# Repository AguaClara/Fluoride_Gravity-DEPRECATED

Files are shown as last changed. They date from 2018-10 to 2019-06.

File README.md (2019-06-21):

# Fluoride Gravity
Our goal is to fabricate a user-friendly gravity-powered fluoride removal system that will be used for research. We aim to make the system easily adjustable so that various parameters can be tested.

See the [Fluoride - Auto repository](https://github.com/AguaClara/fluoride) for more information and previous research.

## Research Advisor
Tigran Mehrabyan (tm545@cornell.edu)

## Current Members
- Sarah Huang (slh268@cornell.edu)
- Cindy Jin (cj359@cornell.edu)
- Simar Kohli (sk2523@cornell.edu)

## Reports and Presentations
* Summer 2018
  - [Summer 2018 Report](https://github.com/AguaClara/Fluoride-Auto/blob/master/Summer%202018%20fluoride%20report/Fluoride_Summer2018.md)
  - [Summer 2018 Symposium](https://docs.google.com/presentation/d/1ikR3Ti14HijdFI1jzeJO_98PFFImXd8VALmxmuq5RYY/edit?usp=sharing)
  - [Summer 2018 Final Presentation](https://docs.google.com/presentation/d/1D4V2ltnIMBQwnw8twaZLWcnoIz6U8TILRAwltYmkqi8/edit?usp=sharing)
* Fall 2018
  - [Fall 2018 Report](https://github.com/AguaClara/Fluoride_Gravity/blob/master/Fall%202018/Fluoride_Grav_Fall2018_Report.md)
  - [Fall 2018 Symposium](https://docs.google.com/presentation/d/1zUhva35X0-_1o3RLzeis4E_ulAN4rfLVFNWJWVaX3iM/edit?usp=sharing)
  - [Fall 2018 Final Presentation](https://docs.google.com/presentation/d/15C-QUAlcFC1fCtsf0PomJqXiPuu_jBoPrGk902efx8c/edit?usp=sharing) and [Video](https://youtu.be/a5wm8xVp81A)
* Spring 2019
  - [Spring 2019 Report](https://github.com/AguaClara/Fluoride_Gravity/blob/master/Spring%202019/Spring%202019%20Report.md)
  - [Spring 2019 Symposium](https://docs.google.com/presentation/d/1IK8bv_c6N9sp4tUEqnVD2FkNc-OZfOIvl0ROv4Z8EFA/edit?usp=sharing)
  - [Spring 2019 Final Presentation](https://docs.google.com/presentation/d/197Uz4GfzHwbOVoRKWKSrQXqSO1M8MqDV9xneFl9WAC0/edit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)
  - [Spring 2019 Final Presentation Video](https://www.youtube.com/watch?v=5M4wX4iei7Y)

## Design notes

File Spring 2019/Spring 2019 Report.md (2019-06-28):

# Fluoride Gravity, Spring 2019
#### Sarah Huang, Cindy Jin, Simar Kohli
#### May 10, 2019
This publication Fluoride, Spring 2019 was developed under Assistance Agreement No. SU-83695001 awarded by the U.S. Environmental Protection Agency to Cornell University. It has not been formally reviewed by EPA. The views expressed in this document are solely those of Sarah Huang, Cindy Jin, and Simar Kohli and do not necessarily reflect those of the Agency. EPA does not endorse any products or commercial services mentioned in this publication.

## Abstract
Fluoride contamination of water is a significant issue faced by nations and people across the globe and can lead to adverse consequences on health (e.g. muscle weakness and atrophy, weakness, fatigue). The Fluoride Gravity team’s objective is to develop a cost-effective, self-sufficient mechanism for extracting excess fluoride from drinking water. The Spring 2019 team hopes to further the gravity-powered system’s efficacy and potentially begin to run field-tests with the device. The application of such a device in real-world scenarios will be predicated upon success seen with the aforementioned field tests.

## Introduction
The majority of AguaClara plants are located in Central America, where the sources of surface water originate from rivers and mountain streams. AguaClara's mission of providing access to safe drinking water for all has motivated the AguaClara team to expand and develop new goals. By considering and analyzing the differences in drinking water collected from groundwater sources in other regions around the world, AguaClara can serve communities outside of Central America who are deprived of access to safe drinking water.

At some locations where there is little to no fluoride in drinking water, fluoride is added in for the purpose of strengthening teeth and deteriorating natural deposits [(NYC DEP, 2016)](http://www.nyc.gov/html/dep/pdf/wsstate16.pdf). However, there are detrimental consequences when there is an excess concentration of fluoride in the water being consumed by inhabitants in the area. For example, there has been moderate to high fluoride pollution in regions such as Algeria, Thailand, Ghana, India, and Iran, whose major source of drinking water comes from groundwater sources. The pollution of groundwater in these regions is due to the mobile dissolution of fluorite, apatite, and topaz from weathered rocks, increasing the levels of fluoride in the groundwater [(Bhattacharya and Samal, 2018)](http://www.isca.in/rjrs/archive/v7/i4/6.ISCA-RJRS-2018-028.pdf). The effects of consuming excess fluoride include dental, skeletal, developmental, neurological, endocrine, reproductive, and carcinogenic issues that affect the health of the communities in areas of high fluoride concentrations [(Bhattacharya and Samal, 2018)](http://www.isca.in/rjrs/archive/v7/i4/6.ISCA-RJRS-2018-028.pdf). Therefore, the World Health Organization (WHO) regulated the concentration limit for fluoride in drinking water to be 1.5 mg/L [(Water-related diseases, 2016)](https://www.who.int/water_sanitation_health/diseases-risks/diseases/fluorosis/en/).

In India, the Bureau of India Standards set an upper limit of fluoride concentrations in drinking water to be 1 mg/L [(Bureau of India Standards, 2012)](https://archive.org/details/gov.in.is.10500.2012). However, more than 65 million Indians consume drinking water above the recommended limit of 1.5 mg/L and some locations in India contain up to 20 mg/L, which risks the health of many communities [(LeChevallier and Au, 2004)](https://www.who.int/water_sanitation_health/publications/9241562552/en/).

AguaClara aspires to achieve the recommended limit of 1 mg/L or lower by the Bureau of India Standards and to implement the gravity-powered system of fluoride removal into the communities with excess concentrations of fluoride. The Fluoride Gravity team will be testing the gravity-powered apparatus with PACl and red dye substituted as fluoride to optimize fluoride removal to achieve residual concentration of less than 1 mg/L. If the gravity-powered fluoride removal apparatus operates in the optimal conditions of removing fluoride to a concentration of 1 mg/L, feasibility analysis on site will be performed to test whether the system can be used in the communities in India, which will allow AguaClara to provide access to safe drinking water in India and other locations that obtain water from groundwater sources.

## Literature Review
### Interaction between Polymeric Aluminum Hydroxide with Fluoride
When hydrolyzed, polyaluminum based coagulants, one of which is polyaluminum chloride, formed mono- and polymeric species [(Gebbie, 2001)](http://wioa.org.au/conference_papers/2001/pdf/paper6.pdf). The interaction between aluminum hydroxide polymer and fluoride led to the formation of several insoluble and soluble products depending on the ratio of total fluoride ion and aluminum ion concentrations, pH, and the total applied fluoride and aluminum concentrations [(Parthasarathy et al., 1986)](http://www.nrcresearchpress.com/doi/abs/10.1139/v94-310). When pH was less than 4, the predominant fluorocomplex was AlF due to the complete dissociation of polymeric aluminum. When the ratio of total fluoride ion and aluminum ion concentrations was between 0.5 and 1, fluoride was observed to precipitate, replacing some of the hydroxide ions in the aluminum hydroxide polymer. When the ratio of total fluoride ion and aluminum ion concentration was greater than 3, there is both precipitate and dissolved complexed fluoride present. It was observed that the optimal conditions for precipitating fluoride was a hydroxide to aluminum ratio of 2.5, a fluoride to aluminum ratio of 0.7, and a pH between 4 and 7. Therefore, experiments should aim to achieve the optimal hydroxide to aluminum and fluoride to aluminum ratios, as well as pH, predicted by literature.

### Mechanisms Governing Removal of Fluoride
Of the potential mechanisms that may play a role in the removal of fluoride with polyaluminum chloride, including surface adsorption, coprecipitation, and precipitation, it appeared that coprecipitation is the main mechanism [(Kowalchuk, 2011)](https://digitalrepository.unm.edu/cgi/viewcontent.cgi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). Coprecipitation is the contamination of a precipitate by an impurity that is otherwise soluble under the conditions of precipitation [(Randtke in Kowalchuk, 2011)](https://digitalrepository.unm.edu/cgi/viewcontent.cgi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). Occlusion and surface adsorption played major roles in this process.

### Interactions Among Fluoride, NOM, and Alum During Coagulation Process
Experimental results from jar tests illuminated mechanisms of behind fluoroaluminum complexation [(Herrboldt, 2016)](https://repositories.lib.utexas.edu/bitstream/handle/2152/39194/HERRBOLDT-THESIS-2016.pdf?sequence=1). When fluoride was present in the system with alum, the residual aluminum increased significantly, indicating that fluoride is likely forming a soluble fluoroaluminum complex. In the removal of fluoride, the presence of natural organic matter (NOM) caused a small decrease in fluoride removal from 50.1% to 45.8%, whereas NOM removal was greatly inhibited by the presence of fluoride [(Herrboldt, 2016)](https://repositories.lib.utexas.edu/bitstream/handle/2152/39194/HERRBOLDT-THESIS-2016.pdf?sequence=1). This indicates that in the removal of fluoride, fluoride was likely outcompeting NOM for complexation with aluminum or adsorption to aluminum solids.

In the precipitation of aluminum with fluoride, fluoride was predicted to act in the following manner: since fluoride is a negatively charged species, fluoride must overcome the negative charge repulsion between particles in order to allow for aggregation. In the precipitation of fluoride with aluminum, the disruption of charges due to the negative repulsion stops collisions and ultimately causes particles to be concentrated at smaller particle diameters [(Herrboldt, 2016)](https://repositories.lib.utexas.edu/bitstream/handle/2152/39194/HERRBOLDT-THESIS-2016.pdf?sequence=1). In this manner, fluoride may inhibit the aggregation of flocs by acting as a stabilizing agent or by inhibiting precipitation. It was hypothesized that fluoride prevented the growth of precipitates by inhibiting interactions between hydroxide and nearby particles. It was also hypothesized that, due to the way that fluoride can replace hydroxide in solids , the formation of aluminum hydroxide complexes would be disrupted.

### pH Dependence of Fluoride Removal
In a study by Gong et al. (2012), fluoroaluminum complexation was found to exhibit pH dependence. At pH values less than 5.0, almost all fluoride existed as fluoro-aluminum complexes, inhibiting its removal by coagulation. At pH levels greater than 8.0, fluoride almost exclusively as free fluoride, indicating that hydroxide has a greater affinity for aluminum at a higher pH [(Herrboldt, 2016)](https://repositories.lib.utexas.edu/bitstream/handle/2152/39194/HERRBOLDT-THESIS-2016.pdf?sequence=1). Thus, all experiments should be run in the optimal pH range for fluoride removal.

### Collection and Analysis of Fluoride samples
An Ion-Selective Electrode (ISE) fluoride probe is used to measure the fluoride concentration of a sample. The following quality-control procedures should be followed.

ISE fluoride probes can only detect solubilized fluoride, and would give inaccurate readings in the presence of Fe3+ and Al3+, such as in cases where polyaluminum chloride is added to the system. Total Ionic Strength Adjusting Buffer (TISAB) solution is added to samples to solubilize the fluoride in the sample and keep the sample at a constant pH of 5-5.5. Temperature should be kept constant with less than a 1 degree Celsius deviation [(EPA Method 9214)](https://www.epa.gov/sites/production/files/2015-12/documents/9214.pdf).

Polyethylene containers, instead of glassware, should be used, since fluoride can adsorb to glass. An Initial Calibration Verification standard and a Continuing Calibration Verification standard should also be used, consisting of solutions of known fluoride concentration within the mean expected fluoride concentration that should be tested. The ICV should be used to test the accuracy of the calibration curve and the CCV should be sued after every 10 samples to ensure that the fluoride probe has not drifted from the calibration curve. These controls should be within 10% of their known values. A control blank containing one part water and one part TISAB should also be used to enhance the accuracy of data in future experiments.

## Previous Work
A coagulation-sedimentation system was developed to extract fluoride from contaminated water. Multiple tests have been run by past teams to analyze the efficacy of the designed system using polyaluminum chloride (PACl) as a coagulant.

The Spring 2016 team continued to develop a more efficient system by testing PACl with clay [(Longo, 2016)](https://drive.google.com/file/d/0B9yahrdDmfVpQ0t0M2NUUkRRNHM/view). While the team was successfully able to create a floc blanket, the Summer 2017 deemed clay to be not as necessary as it increased the effluent turbidity of the system, [(Akpan et al., 2017)](https://github.com/AguaClara/Fluoride-Auto/blob/master/FluorideReportSp18.md), and therefore ran tests with just fluoride and PACl. However, it was soon realized that the system would begin to fail after just 10 hours. In conjunction with the Summer 2017 High Rate Sedimentation Team, a new reactor was able to boost the time to failure and allow for increased upflow velocities. It was determined that the most efficient upflow velocity was 1.5 mm/s [(Pang et al., 2018)](https://github.com/AguaClara/Fluoride_Gravity/blob/master/Fall%202018/Fluoride_Grav_Fall2018_Report.md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). The same team continued to conduct experiments with varying concentrations of PACl in order to determine the most effective concentration of PACl to be delivered to the system.

The 2018 cycle of teams managed to focus on developing a robust, gravity-powered system [(Akpan et al., 2017)](https://github.com/AguaClara/Fluoride-Auto/blob/master/FluorideReportSp18.md). The process through which this system works is displayed in the schematic below (Figure 1).

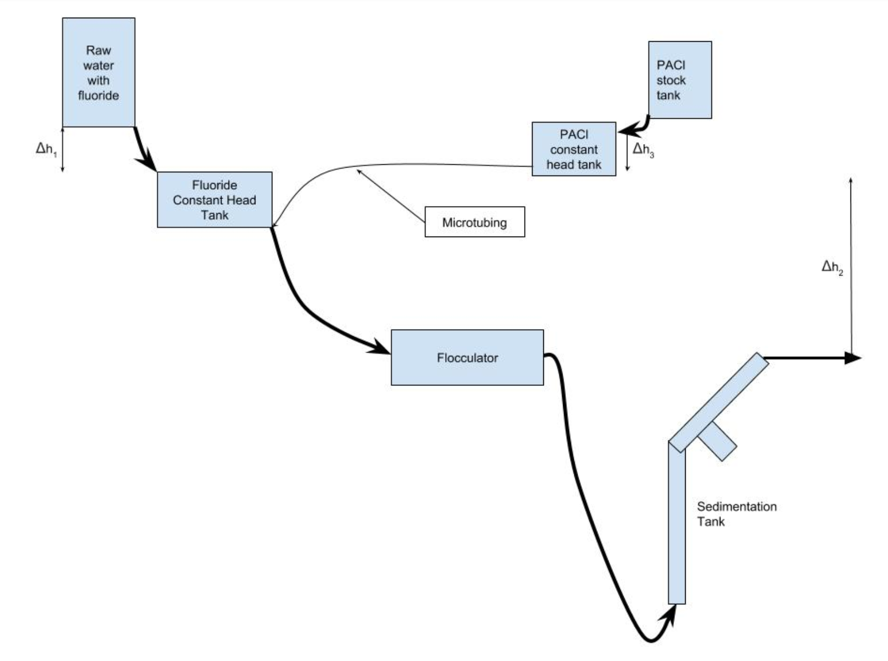
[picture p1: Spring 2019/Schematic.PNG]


**Figure 1:** A schematic for the gravity-powered system with differences in height generated power.

Some of the major designs of the model were created by the Spring 2018 team, and focused on deploying float valves to maintain a constant amount of water flowing through the system. Since the concentration of the PACl solution remained constant in the stock tank, a calculation of flow rate provided insight into the concentration of PACl actually entering in the system [(Pang et al., 2018)](https://github.com/AguaClara/Fluoride_Gravity/blob/master/Fall%202018/Fluoride_Grav_Fall2018_Report.md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).

The Summer 2018 team furthered the flexibility of the system by including sliders for controlling height differences between different tanks and pipes (Figure 2). This provided the ability for teams to adjust the flow rate within the system.

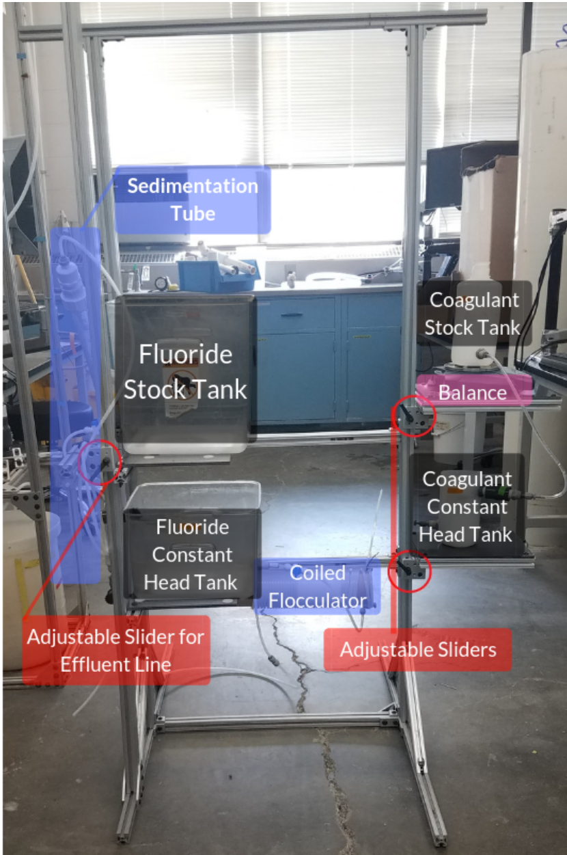
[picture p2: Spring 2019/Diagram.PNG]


**Figure 2:** Adjustments made by the Summer 2018 team to the set-up to allow for height variations.

The Summer 2018 team continued to conduct tests on varying PACl concentrations and fitted new data to the Langmuir adsorption spectrum created by the Fall 2017 team (Figure 3). Concentrations of fluoride (range: 3 to 20 mg/L) and PACl (range: 10 to 50 mg/L) were tested. A Langmuir isotherm was applied to the data to obtain a new uptake vs effluent model [(Pang et al., 2018)](https://github.com/AguaClara/Fluoride_Gravity/blob/master/Fall%202018/Fluoride_Grav_Fall2018_Report.md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).

The following equation was used: $$ \frac{C_e}{q_e} = \frac{1}{q_e}C_e+\frac{1}{K_L\cdot q_m} $$

where $C_e$ is the equilibrium concentration of the adsorbant, $q_e$ is the amount adsorbed at equilibrium, and $K_L$ and $q_m$ are Langmuir constants which are related to adsorption capacity and energy of adsorption.

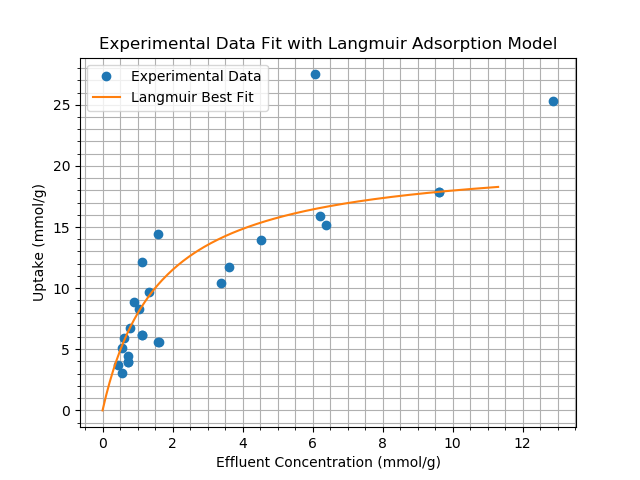
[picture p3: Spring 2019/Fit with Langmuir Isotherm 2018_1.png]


**Figure 3:** A Langmuir isotherm fitted with data from the Summer 2018 team. The calculated $R^2$ value was 0.7611.

In Fall of 2018, two teams were made from the original Fluoride team: [Fluoride Gravity](https://github.com/AguaClara/Fluoride_Gravity) worked to make the gravity-powered apparatus more efficient, and [Fluoride Auto](https://github.com/AguaClara/Fluoride-Auto) spearheaded the development of an adsorption model by running more bench experiments [(Pang et al., 2018)](https://github.com/AguaClara/Fluoride_Gravity/blob/master/Fall%202018/Fluoride_Grav_Fall2018_Report.md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).

Finally, the Fall 2018 team prioritized developing a mechanism or process for measuring coagulant flow rate within the system. An IV drip was installed within the system along with microtubing. While headloss still occurred, the team adjusted the height of the coagulant constant head tank to modify flow rate. The drip chamber was noted to substantially streamline the process of measuring flow rate [(Pang et al., 2018)](https://github.com/AguaClara/Fluoride_Gravity/blob/master/Fall%202018/Fluoride_Grav_Fall2018_Report.md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).

The goal of the Spring 2019 Fluoride team was to modify any necessary parts to the system developed over the past few years by previous Fluoride teams, begin to run comprehensive tests on red-dye within the system, and finally proceed to testing fluoride solutions within the system itself.

## Methods
### Experimental Apparatus
The gravity-powered apparatus was constructed as according to the fabrication manual in the [Fluoride Gravity Fall 2018 report](https://github.com/AguaClara/Fluoride_Gravity/blob/master/Fall%202018/Fluoride_Grav_Fall2018_Report.md).

### Redesigning of System
Despite the foundational work of the apparatus laid by the Fall 2018 team, it was determined the system needed to focus on having modifications in four major areas:

* Development of new method of introduction of polyaluminum chloride (PACl)
* Size reduction of fluoride constant head tank
* Increasing length of flocculator
* Addition of bottom geometry to sedimentation tube

However, most of the other aspects of the system were kept the same (e.g. sliders for moving tanks up and down, the presence of stock and constant head tanks, and the sedimentation tube itself).

The overall set up of the current system is shown in Figure 4.

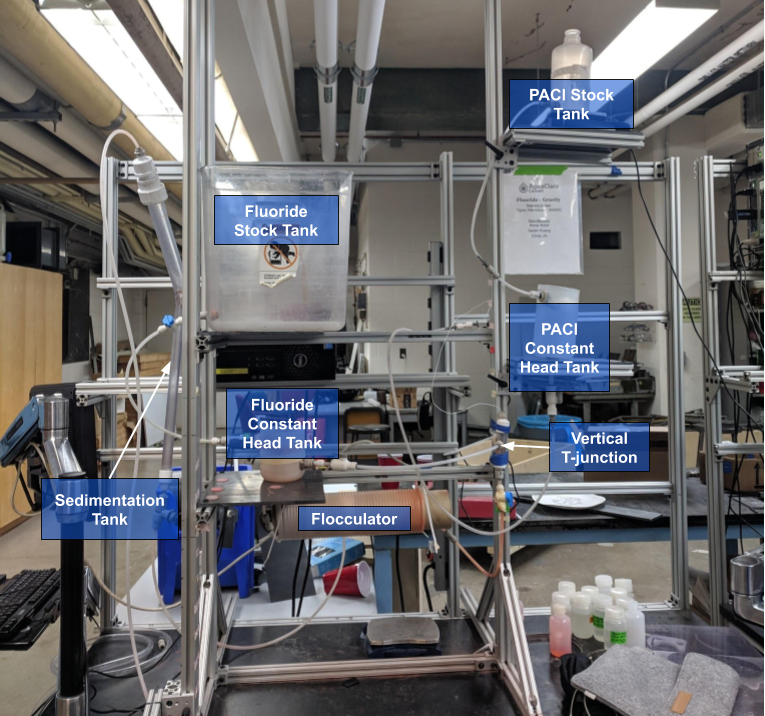
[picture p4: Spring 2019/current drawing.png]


**Figure 4:** An overview of the newly modified system.

### Introduction of Polyaluminum Chloride
The principal reason for modifying the method by which coagulant (PACl) was introduced into the system was the inefficiency of the IV drip chamber system set up by the Fall 2018 team (Figure 5).

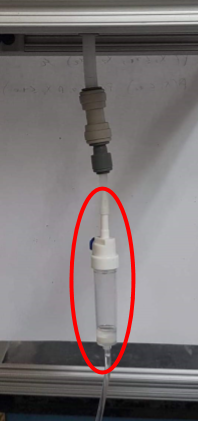
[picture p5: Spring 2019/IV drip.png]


**Figure 5:** The IV drip system that was implemented by Fall 2018 team. IV drip chamber was connected to coagulant constant head tank and flowed into flocculator.

When the system was run under the previous set-up, hydrostatic pressure from the flocculator would drive water into the drip chamber, filling it completely by the time the system was restarted. This resulted in the team having to consistently flush out the chamber. However, this led to air being introduced into the tubing and stopping flow within the system, entirely [(Pang et al., 2018)](https://github.com/AguaClara/Fluoride_Gravity/blob/master/Fall%202018/Fluoride_Grav_Fall2018_Report.md).

Several changes were thus made to optimize the ease of use of the apparatus. The IV drip chamber was removed due to previous difficulties in starting the system.

#### First Redesign: Direct Mixing in Fluoride Constant Head Tank
The T-joint that allowed PACl to be dosed directly into the flocculator was first removed, allowing the fluoride constant head tank to be directly connected to the flocculator (Figure 6).

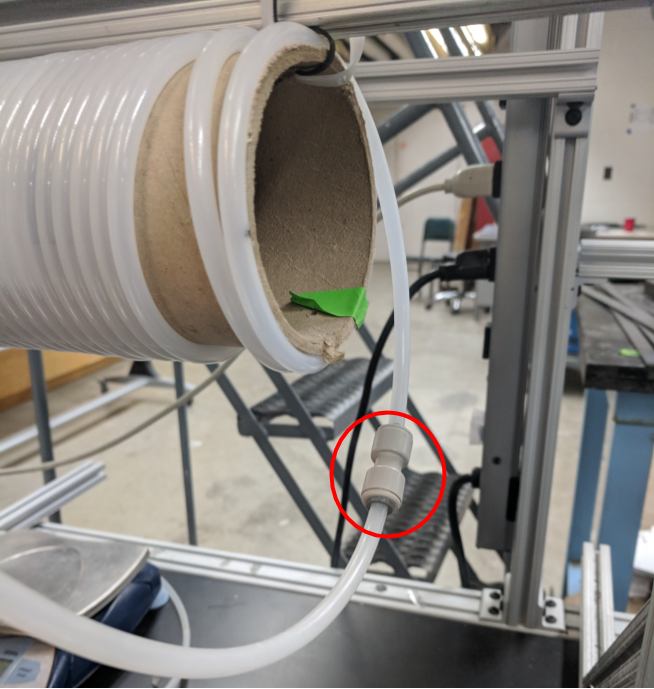
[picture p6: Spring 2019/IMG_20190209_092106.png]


**Figure 6:** New connection linking the fluoride constant head tank with the flocculator.

The team decided to directly drip the coagulant into the fluoride constant head tank by taping the end of the microtubing to the side of the tank (Figure 7). However, given that the size of the actual constant head tank was too large for proper mixing of the coagulant to occur, the constant head tank was reduced to a smaller size to allow for better mixing of the coagulant in the actual fluoride solution.

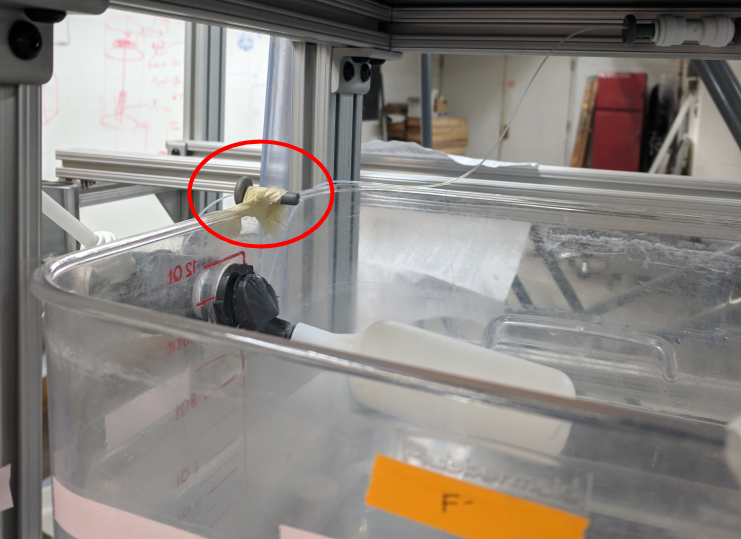
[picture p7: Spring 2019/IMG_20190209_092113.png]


**Figure 7:** Microbore tubing connected to the PACl system allows PACl to drip directly into the fluoride constant head tank.

However, two major problems were noted with this procedure. The first was that coagulation began in the tank as a result of dripping PACl directly into the tank. This could risk failure of the system if the coagulation blocked the outflow from the fluoride constant head tank. The second problem was a non-homogenous mixture was formed within the constant head tank, resulting in lower flocculation.

As a result, the team focused on creating a more effective drip system for introducing PACl while also being able to monitor flow rate/the rate of introduction of PACl into the system.

#### Second Redesign: Addition of T-Junction
The team determined that a new mechanism was necessary for effectively introducing the PACl into the system, one that would allow for easy calculation of flow rate, prevent re-introduction of air within the system, and create essentially a homogenous solution flowing into the flocculator.

As a result, the team decided that a T-junction could be used in between the outflow of the fluoride constant head tank and the flocculator. The third hole on the T-junction would be connected to a translucent pipe in which the PACl microtubing would drip the coagulant into (Figure 8). Holes were drilled in the translucent pipe to ensure that the dripping mechanism was open to atmospheric pressure.

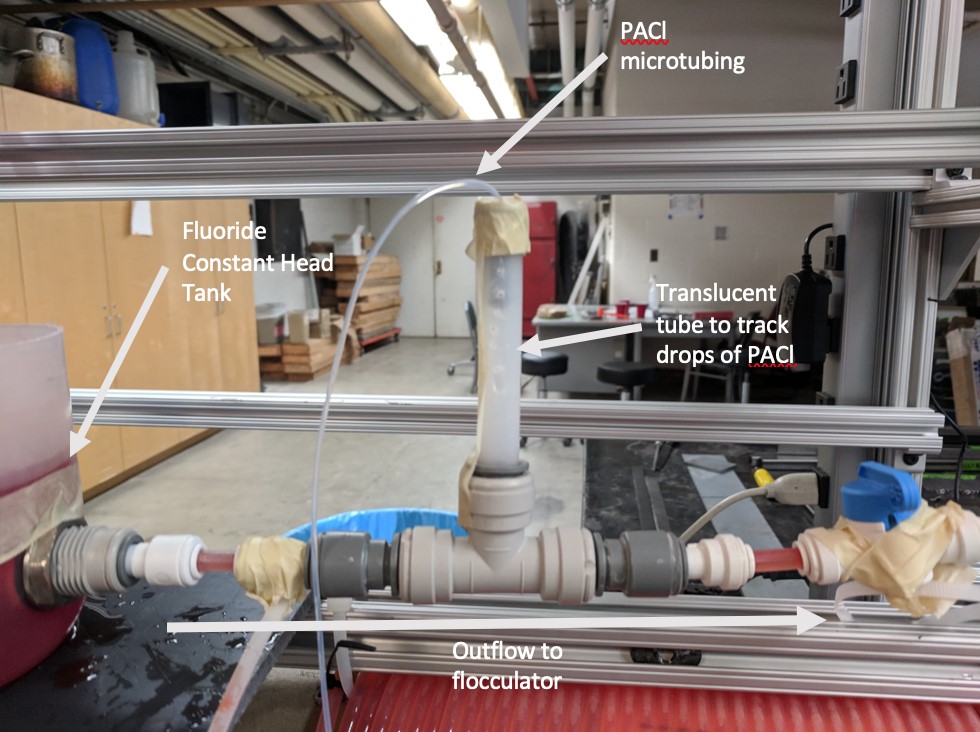
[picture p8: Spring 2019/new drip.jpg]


**Figure 8:** The system works by dropping PACl in to the solution flowing out of the system (towards the flocculator). Flow rate can be calculated by counting the volume of PACl dispensed in a certain period of time, producing a flow rate. Alternatively, the number of drops dispensed can be tracked by shining a light through the translucent tubing. The volume of one drop can be calculated, multiplied by the number of drops introduced in a time frame, and divided by the total time taken.

The overall set up of the system until this point is shown in Figure 9.

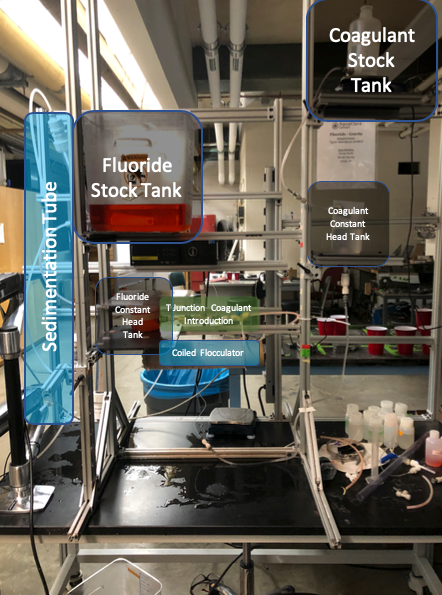
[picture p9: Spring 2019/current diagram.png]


**Figure 9:** An overview of the modified system.

#### Third Redesign: Fabrication of Clear T-Junction
Thus far, the system had experienced inconsistency in the size of flocs generated when PACl and red dye were mixed. It was hypothesized that the T-junction did not allow for the complete mixing of PACl and red dye.

In order to elucidate the mechanisms behind PACl and red dye mixing and binding, a clear T-junction was fabricated to be able to observe the behavior of PACl and red dye throughout the system.

The T-junction was fabricated by using a three inch segment of a clear PVC pipe that was 1 inch in diameter. Caps were fitted on both ends to allow connections to ¼ inch tubes. A fitting allowing for connection to a ¼ inch tube was drilled into the top of the PVC pipe, forming a T.  The drip system used previously was reconnected to the top of the fabricated T-junction.

The tube connecting the fluoride constant head tank and the T-junction was lengthened in order to prevent backflow, as backflow seemed to be an issue with the previous system. However, it is inconclusive whether this change was effective. A valve was also added between the fluoride constant head tank and the T-junction to allow for ease of maintenance in the case that the T-junction needed to be cleaned (Figure 10).

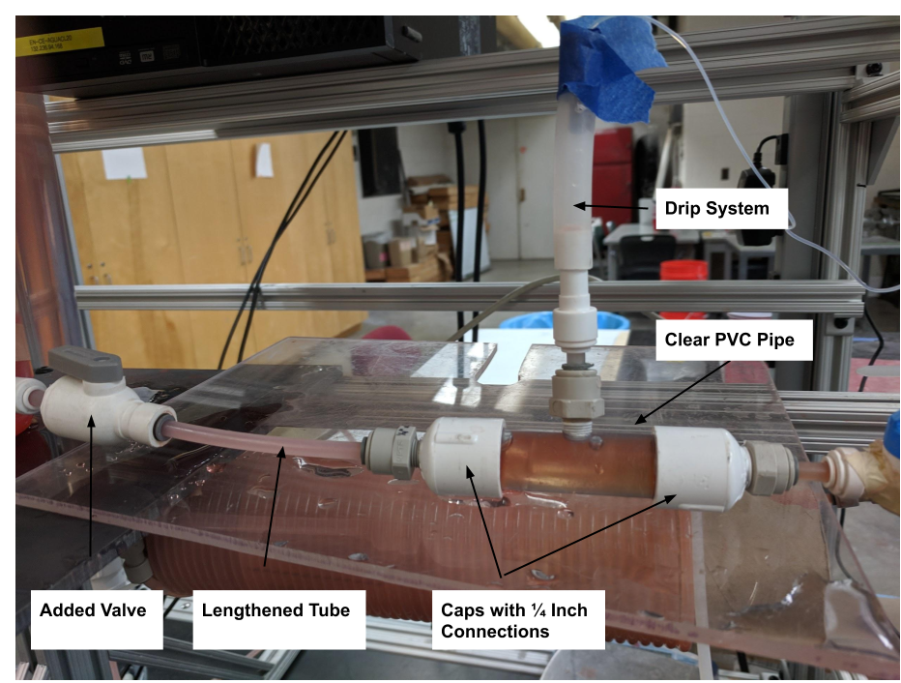
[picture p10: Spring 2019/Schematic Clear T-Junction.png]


**Figure 10:** A diagram of the fabricated T-junction and the new additions to the system, including the lengthened tube to prevent backflow and an added valve for ease of maintenance.

#### Fourth Redesign: Vertical Modification of T-Junction
After the development of a horizontal T-junction with a clear pipe (Figure 10), multiple tests were conducted on the system. However, it was noted that the system was continuing to fail to flocculate. When the clear piping within the T-junction was observed, it was noted that the red dye and PACl separated (either due to density differences or possible laminar flow). As a result, due to a lack of mixing between the two solutions, no flocs were being observed.

Thus, the team decided to turn the T-junction 90 degrees (thereby making it vertical) (Figure 11). The PACl was still being introduced from the top by microtubing; however, the solution now left the T-junction from the bottom. This was noted to contribute to better mixing, as the system began to flocculate and there was no further separation of the PACl and red-dye.

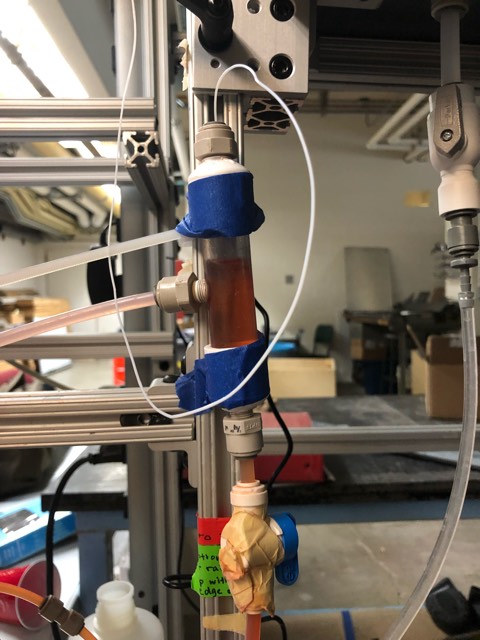
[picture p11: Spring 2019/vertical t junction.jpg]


**Figure 11:** Vertical T-junction with PACl introduced at top and dye introduced at the left

### Fabrication of New Flocculator
#### Increasing Flocculator Length
The length of the flocculator was increased to provide greater amount of time for flocculation. Specifically, the newly constructed flocculator coils around the main cardboard cylinder 49 times, and was constructed from 46 ft. of tubing (Figure 12).

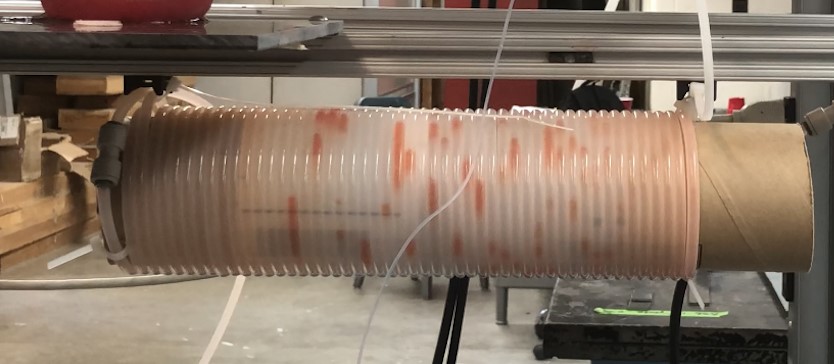
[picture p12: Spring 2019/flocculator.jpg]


**Figure 12:** The flocculator (lengthened to 46 ft. of tubing) in the system.

The reasoning behind increasing the flocculator’s length was that the PACl may need more time mixing effectively with the solution to produce the flocs necessary for filtration. Furthermore, providing more room and opportunity for collision between PACl molecules and the fluoride/red-dye within the system creates a more effective flocculation system and overall system.  

### Improving Sedimentation Processes
#### Addition of Bottom Geometry in Sedimentation Tube
The red dye flocs were observed to be clumping together at the bottom of the sedimentation tube, which resulted in the formation of a gel rather than a fluidized bed (Figure 13).



**Figure 13:** Before the addition of the bottom geometry, the formation of a gel is seen on the bottom of the sedimentation tube, which prevents the flow of clean water to exit the sedimentation tube and prevents the removal of the red dye particles from the PACl solution.

In order to prevent the formation of a gel at the bottom of the sedimentation tube and to effectively remove flocs, a bottom geometry was added to the bottom of the sedimentation tube to increase recirculation and collisions of the flocs to promote the formation of a fluidized bed (Figure 14). The bottom geometry was obtained from the [High Rate Sedimentation: Bottom Geometry team](https://github.com/AguaClara/HRS-Bot-Geo).

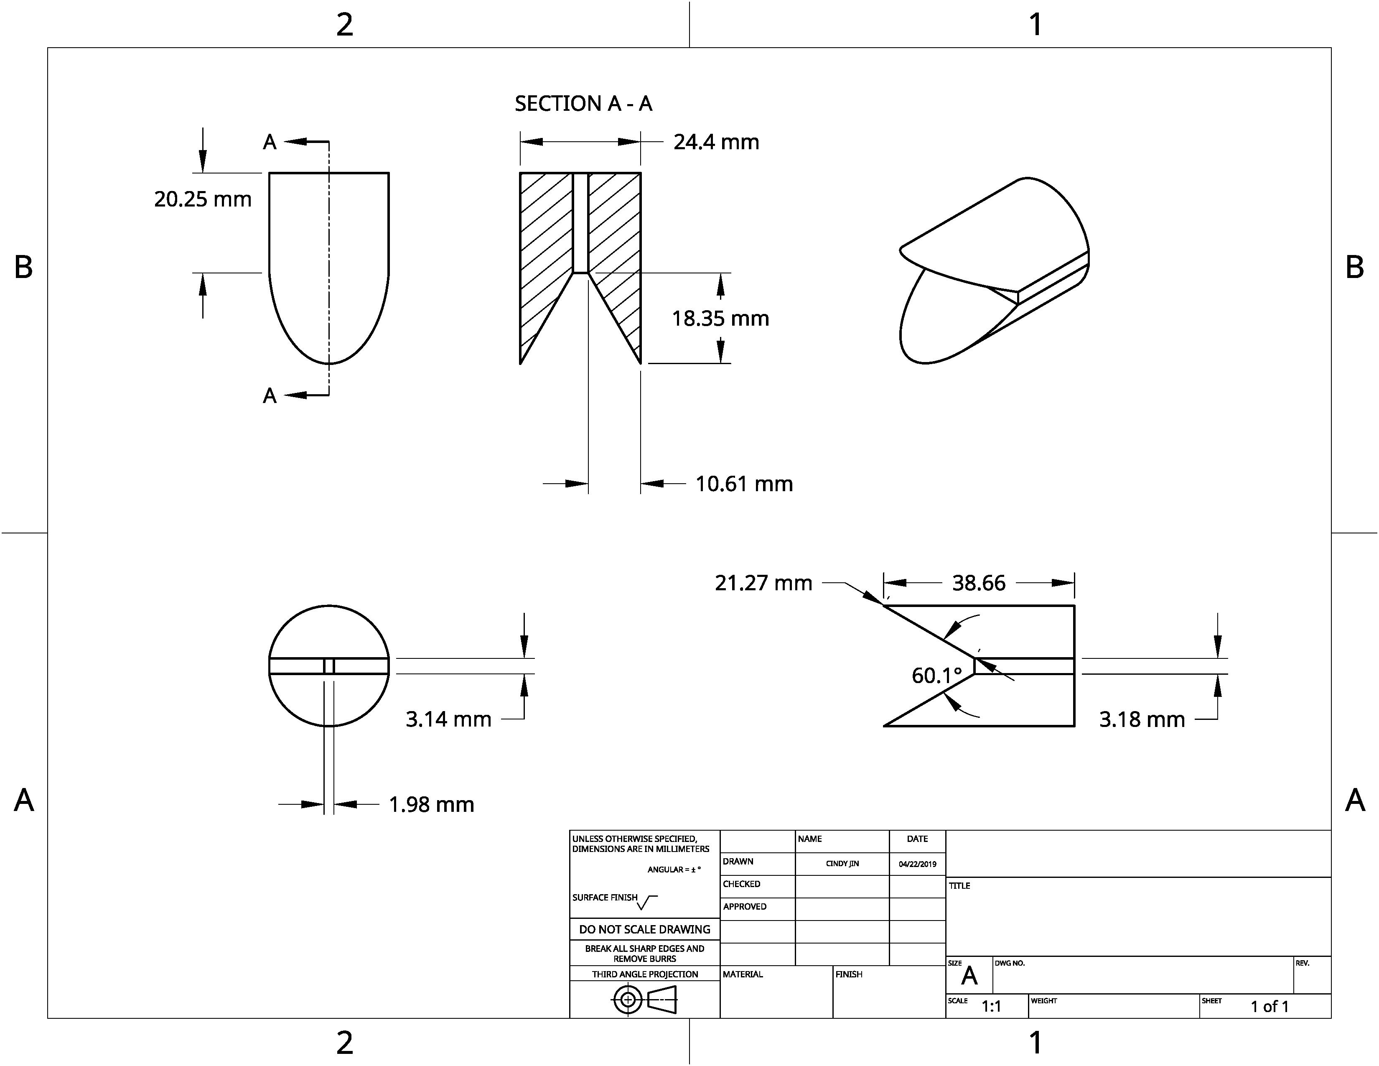
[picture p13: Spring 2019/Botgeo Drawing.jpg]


**Figure 14:** 2D scaled drawing of the bottom geometry that was added to the sedimentation tube.

The bottom geometry helped with the removal of flocs in the system because the slanted angle in the bottom geometry allowed for flocs to resuspend and change in flow direction rather than fall to the bottom of the sedimentation tube (Figure 15). The fluidized bed allowed for the flocs to move along the sedimentation tube and down the waste line, and the clean water to move past the waste line and exit the effluent line. Thus, the flocs were able to form a fluidized bed and increase the removal of red dye flocs from the PACl solution.



**Figure 15:** The formation of a fluidized bed is seen after the addition of the bottom geometry.

#### Jar Testing
In previous runs of the gravity powered system in which flocculation was successful, it was observed that red dye particles continued to float through the sedimentation tube regardless of its upflow velocity. That is, even when the system was stopped, all of the red dye flocs floated to the top of the sedimentation tube.

To test whether this result was specific to mechanics of flocculation that could perhaps change the properties of red dye flocs, a jar test was conducted. In one jar, a magnetic stirrer was used to rapidly mix the solution to increase collision rates. The other jar contained solution directly obtained from the system.

Plastic beakers with 420 $\mu$L of PACl was mixed with 100 $\mu$L of red dye in 400 mL of water. The solution was using a stir bar for 15 minutes before leaving the solution to settle.

This was compared to a solution of red dye-PACl flocs collected directly from the experimental apparatus after flocculation. The system concentration of PACl was 40 mg/L, and the red dye concentration used was identical to the independent test. The solution after flocculation was added to a beaker initially containing 200 mL of water to simulate conditions in the sedimentation tank. The flocculation solution was added to the beaker it was roughly the same color as the first independently created solution. The solution was not stirred and was allowed to settle directly after the addition of flocs.

## Results and Analysis
### Determining Coagulant Flow Rate
The flow rate of PACl was determined to have a linear relationship with the height differential between the fluoride constant head tank and the PACl constant head tank by the [Fluoride Gravity Fall 2018 team](https://github.com/AguaClara/Fluoride_Gravity/blob/master/Fall%202018/Fluoride_Grav_Fall2018_Report.md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). It was hypothesized that the decoupled PACl system would exhibit the same linear relationship with the change in height. The flow rate of the PACl entering the decoupled fluoride system was determined in two different methods: gravimetrically and volumetrically.

#### Gravimetric Method: Flow Rate of PACl During Direct Mixing of PACl Into Fluoride Constant Head Tank
The flow rate of the coagulant was determined by measuring the change in mass of the PACl stock tank over a period of time. This was then converted to volumetric flow rate. This was mode of measurement was conducted only with the direct mixing of the PACl into the fluoride head tank redesign of the system. The balance was connected to ProCoDA to measure the change in mass. The volumetric flow rate of the PACl coagulant entering the fluoride system was measured at several height differences (Figure 16).

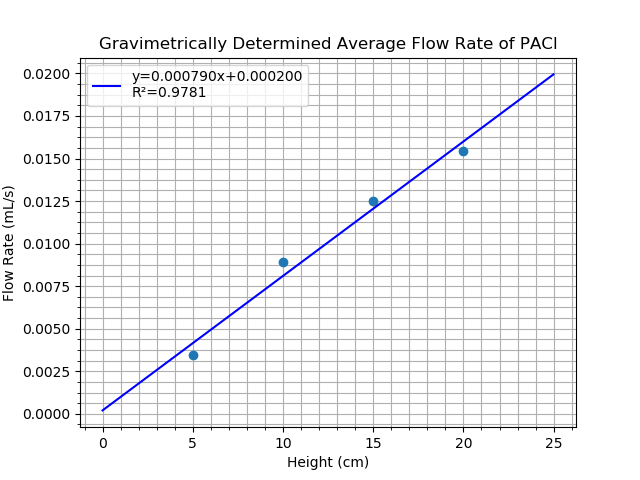
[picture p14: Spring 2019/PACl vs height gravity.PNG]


**Figure 16:** The flow rate of the PACl system was plotted against the change in height between the fluoride constant head tank and the PACl constant head tank. The data exhibits a strong positive correlation, indicating a direct relationship between flow rate and change in height.

The slope of the best fit line of the flow rate of the PACl system versus the difference in height between the fluoride constant head tank and the PACl constant head tank graph was calculated to be $7.9*10^{-4} mL*s^{-1} * cm^{-1}$, demonstrating the flow rate of PACl flowing into the fluoride system increases by $ 7.9*10^{-4} $ mL/s per cm of height difference raised.

#### Volumetric Method: Flow Rate of PACl After Addition of T-Junction
Using a 10 mL graduated cylinder, the flow rate of the PACl entering the fluoride system was also determined by measuring the time the PACl coagulant took to drip into the fluoride system to a volume of 2 mL. This was only conducted with the addition of the T-junction redesign of the system. The flow rate of the PACl entering the fluoride system was measured while varying the height difference between the fluoride constant head tank and the PACl constant head tank and doing three trials for each height difference. The data also exhibits a strong positive correlation indicating a direct relationship between flow rate and the difference in height between the coagulant constant head tank and the fluoride constant head tank (Figure 17).

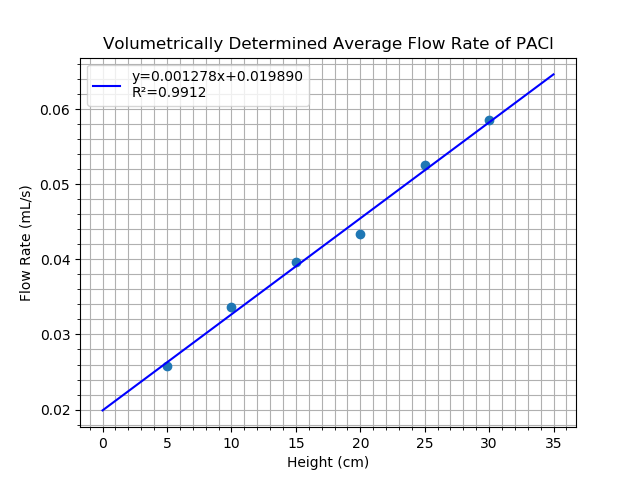
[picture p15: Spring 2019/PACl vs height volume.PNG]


**Figure 17:** The flow rate of the PACl system versus the difference in height between the fluoride constant head tank and the PACl constant head tank graph displaying a strong correlation between flow rate and change in height.

The slope of the best fit line of the flow rate of the PACl system versus the difference in height between the fluoride constant head tank and the PACl constant head tank graph was calculated to be $1.28*10^{-3} mL*s^{-1}* cm^{-1}$, which demonstrates the flow rate of PACl flowing into the fluoride system increases by $7.9*10^{-4}$ mL/s per cm of height difference raised.

The strong correlation implies that the relationship in the decoupled system operates in the same manner as the previously linked system with the IV drip chamber.

#### Volumetric Method: Flow Rate of PACl Using Vertical Clear T-Junction System

The flow rate of the PACl entering the system was recalculated after modifying our system to have an elongated microtubing for the PACl to enter the system in the vertical clear T-junction. The flow rate was calculated volumetrically by measuring the amount of time it took the coagulant to drip into a graduated cylinder to 10 mL for each height difference between the fluoride constant head tank and the PACl constant head tank. The data demonstrates a linear correlation between the height difference of the constant head tanks and the PACl flow rate entering in (Figure 18).

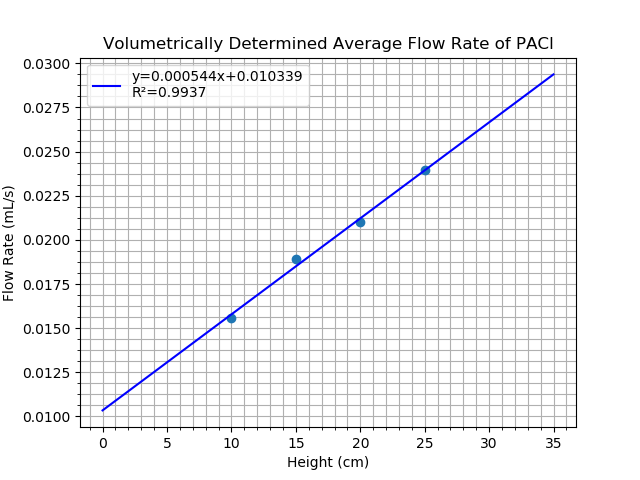
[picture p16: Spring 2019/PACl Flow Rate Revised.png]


**Figure 18:** The flow rate of the PACl system versus the difference in height between the fluoride constant head tank and the PACl constant head tank graph displaying a strong correlation between flow rate and change in height.

With the modified changes and elongated microtubing, the PACl flow rate entering the system decreased significantly as well as the rate in which the PACl flow rate changes with respect to the constant head tanks' height difference. This change in PACl flow rate occurred because the elongated microtubing increased the frictional head loss and residence time in the microtubing.

#### Comparison Between Gravimetric Method and Volumetric Method
The value of the coefficient of determination, $R^2$, was higher in the volumetric analysis graph (Figure 16) than the $R^2$ value of the gravimetric analysis graph of the PACl flow rate versus height (Figure 15). Therefore, the data collected from volumetric method is more accurate because the mass balance's readings was rounded to the hundredths place. The lower accuracy of the gravimetric method was due to the fact that the mass balance scale only measured the change in mass when the float valve in the constant PACl head tank opens, which gave inaccurate results as the float valve opens only when the water level drops. The mass did not change when the water level is level with the valve. Therefore, the change in mass was not constant which provides inaccuracy in the measurements.  However, the gravimetric method used ProCoDA and a mass balance with automated time and mass readings while the volumetric analysis was estimated with the human eye and timed manually, which accounted for human error. As a result, several trials were done to increase the accuracy and precision of the measurement of the volumetric flow rate of PACl entering the fluoride system.

The determination of the coagulant flow rate allowed the team to control and optimize the concentration of PACl entering the fluoride system.

### Determining Binding of PACl
#### First Redesign: Direct Mixing in Fluoride Constant Head Tank
The system was run in reverse, with red dye run through the PACl system to determine the extent of mixing. PACl solution was added to the fluoride system to determine the extent of coagulation and whether the solution would successfully flocculate. The system was run with a upflow velocity of 0.76 mL/s.

The red dye appeared to coagulate at the surface of the constant head tank. The water entering the flocculator was less red than the water in the constant head tank, implying that precipitation occurred in the constant head tank, lessening the extent of flocculation in the flocculator itself.

#### Second Redesign: Addition of T-Junction
The system was run in the correct orientation, with the red dye run through the fluoride tanks and PACl run through the PACl stock tanks. The PACl stock concentration was 1000 mg/L, and the red dye stock solution was diluted by a factor of 1/4000 (1 mL red dye for 4 L of water). The system was run at an upflow velocity of 0.48 mL/s.

The red dye was able to bind with PACl in the flocculator, allowing for successful flocculation. However, flocculation was inconsistent and the ability of the system to flocculate varied from day to day.

#### Third Redesign: Use of Clear T-Junction Horizontally
The system was tested with the new clear T-junction at different effluent flow rates to see if the PACl and red dye were mixing together effectively at the intersection. The clear T-junction made it possible to see that there was a clear layer of PACl settling on the bottom and not binding with the red dye (Figure 19).

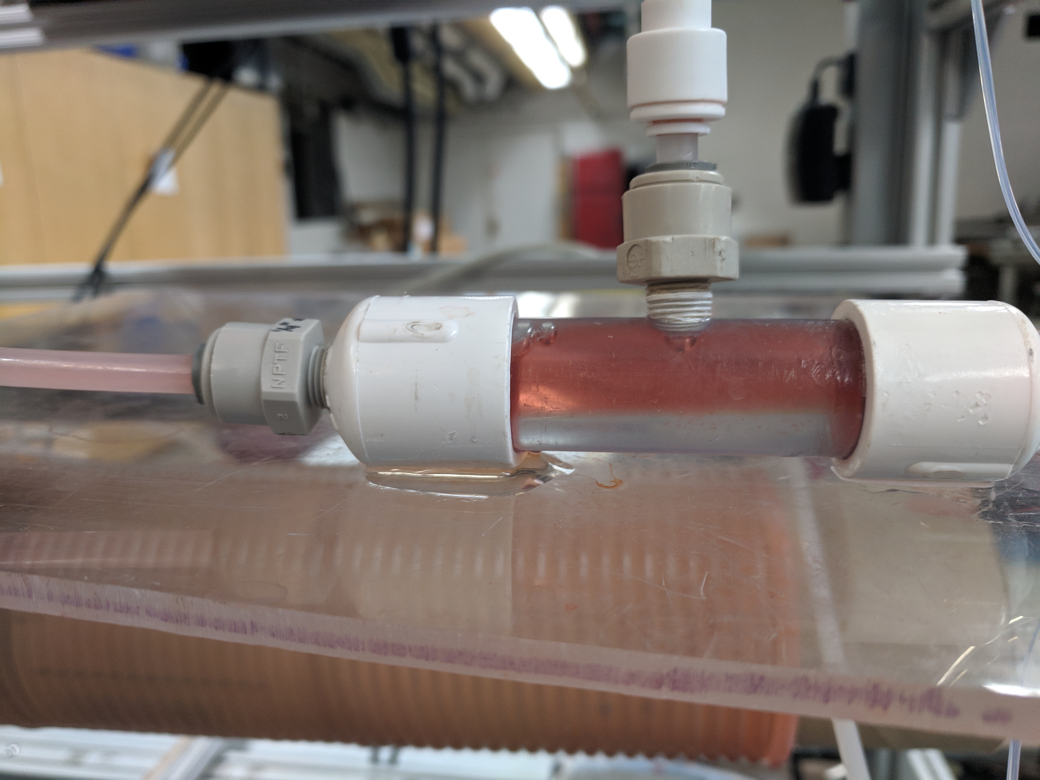
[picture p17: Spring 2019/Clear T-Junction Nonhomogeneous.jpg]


**Figure 19:** The introduction of PACl at the T-junction was seen to form a nonhomogeneous solution and the red dye and PACl were seen to not effectively mix together.

All tests were conducted at PACl flow rate of 0.0337 mL/s, which was the flow rate that previously allowed the system to flocculate. At the effluent rate of 0.69 mL/s, the PACl was seen to effectively bind with red dye as the formation of flocs were seen in the clear T-junction, but there were some flocs moving the opposite way of the fluid flow as seen in Figure 20, which may contribute a smaller flow rate of flocs entering the flocculator. At all other effluent flow rates, flocs were not observed.



**Figure 20:** At the system effluent rate of 0.69 mL/s, the red dye and PACl were seen to bind together and form flocs, but some of the flocs were seen to resist against the fluid flow in the clear T-junction.

These observations demonstrated that the red dye and PACl solutions were not effectively binding at the site of mixing and progressing to the flocculator for this concentration of PACl and all effluent flow rates. As a result, introducing PACl into the system in this manner was ineffective and should be revised.

### Determination of Effluent Flow Rate
In all prior experiments, the effluent flow rate was manually measured each time with a graduated cylinder. A curve based on the change in height of the effluent tube and the flow rate was established in order determine the flow rate of the system more easily.

To establish this curve, the effluent flow rate of the entire system was determined volumetrically. The team changed the height of the effluent pipe below the point of zero flow from 5 cm to 40 cm, with intervals of 5 cm. At each particular height, a 10 ml graduated cylinder was used to measure the volume of effluent water leaving the system in a particular period of time. Three trials were conducted and an average effluent flow rate was calculated, per height.

#### Effluent Flow Rate with Original T-Junction
The data was plotted, and a linear regression was fitted to measure the effluent flow rate at varying heights (Figure 21).

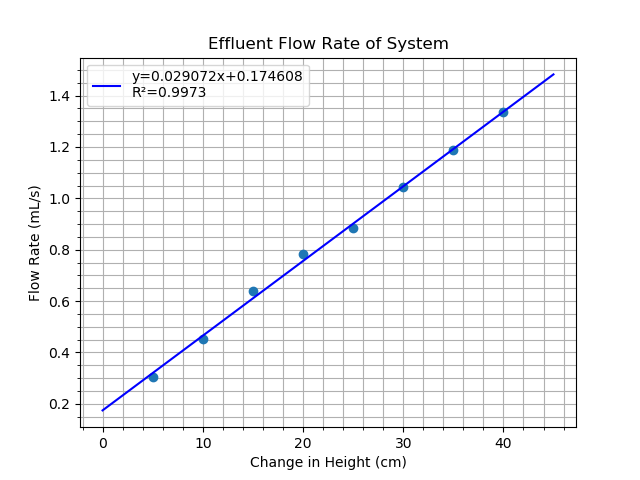
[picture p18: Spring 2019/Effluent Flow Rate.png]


**Figure 21:** The effluent flow rate graph determined volumetrically from a height difference of 0 cm to 40 cm from the point of zero flow using the original T-junction in the system.

When running the system at approximately 0.48 mL/s (with the effluent pipe located at the 10 cm mark), the system was noted to generate large flocs within the flocculator, indicating that the particular velocity of the system seemed to be working appropriately. Even when the system’s velocity was decreased to 0.34 mL/s, large flocs were still forming.

In light of this, the team decided to increase the effluent velocity of the system to analyze the impact of making the system faster. As a result, smaller flocs were noted to form, even to the point that the flow rate became too fast for significant flocs to form (flow rate > 30 cm).

However, from previous research, it was noted that a flow rate of 0.76 mL/s has been the most effective at floc formation as well as speed/efficiency of the system.

Yet, upon re-testing the system after determining the optimal effluent flow rate, as well as with other flow rates that previously worked (e.g. 0.48 mL/s, 0.38 mL/s, etc.), the system failed to flocculate. It was noted that the dye seemed to be lighter than usual, as well as the dye continued to clump within the sedimentation tank. The inconsistencies in flocculation persisted, but were solved upon using the vertical clear T-junction.

#### Effluent Flow Rate with Horizontal Clear T-Junction
The effluent flow rate of the system was tested again after lengthening the tube exiting the fluoride constant head tank and replacing the T-junction with a clear T-junction to accurately account for the changes to the system. The effluent flow rates of the system were tested in the same volumetric way and plotted against the change in height (Figure 22).

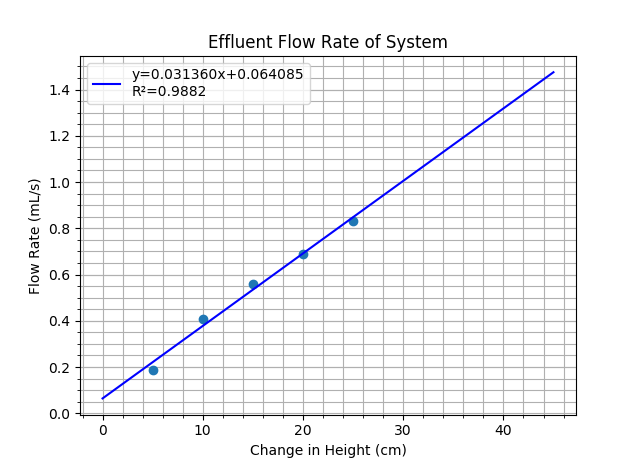
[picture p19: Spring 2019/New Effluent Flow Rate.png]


**Figure 22:** The effluent flow rate graph of the effluent flow rate determined volumetrically from a height difference of 0 cm to 40 cm from the point of zero flow using the redesigned system with the clear T-junction set horizontally.

Compared to the effluent flow rate of the system before the changes of the clear T-junction and the elongated tube, the effluent flow rate of the revised system was running at slower rates at the same height differences (Figure 20 and 21). The slower flow rates were due to the additional friction factors the red dye solutions experienced from the elongated tube. However, the rate at which the effluent flow rate changes with the difference in height was seen to be higher than that of the system before the changes because the slope of the best fit line of the effluent flow rate after the changes made is greater (Figure 21 and 22).

#### Effluent Flow Rate with Vertical Clear T-Junction System

The effluent flow rate of the system was tested again after vertically orienting the clear T-junction and lengthening the PACl microbore tubing to accurately account for the changes to the system. The effluent flow rates of the system were tested in the same volumetric way and plotted against the change in height between the constant head tanks (Figure 23).

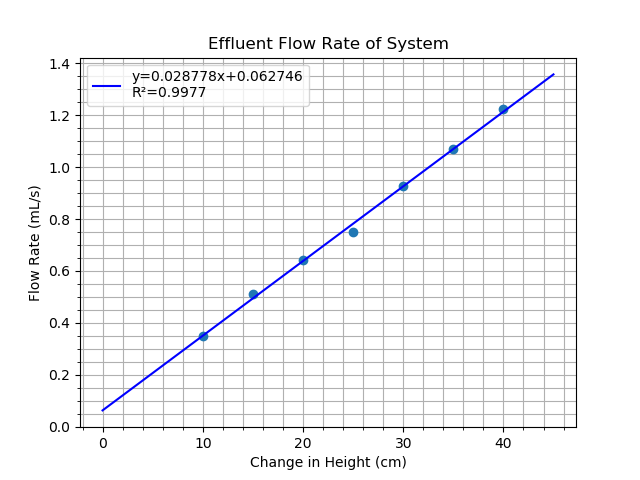
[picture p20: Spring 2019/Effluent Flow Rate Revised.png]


**Figure 23:** The recalculated effluent flow rate graph determined volumetrically from a height difference of 0 cm to 40 cm from the point of zero flow using the clear T-junction oriented vertically in the system.

 The effluent flow rate of the vertical T-junction system was running at slower rates at the same height differences compared to the effluent flow rate of the system before the change of orientation of the T-junction and the elongated microbore PACl tube (Figure 22, 23). The slightly slower flow rates were due to the additional friction head loss of the elongated microbore tubing that significantly slowed the flow rate of PACl entering the system. Furthermore, the rate that the effluent flow rate changed with the difference in height between the constant head tanks was seen to be lower than that of the system before the changes in orientation of the T-junction and the elongated PACl microtubing. This was exhibited by the fact that the slope of the best fit line of the effluent flow rate was smaller after the changes were made (Figure 22 and 23).

### Conditions for Flocculation
#### Effects of Effluent Flow Rate
In the first redesign of the system in which the microbore tubing dripped directly into the fluoride constant head tank, it was observed that no flocs or precipitates were observed when the system was run at the previously successful effluent flow rate of 0.76 mL/s. It was observed that the water exiting the effluent line had a large red dye concentration, suggesting an inability of PACl to bind with red dye at this high velocity.

When the system was run at 0.10 mL/s, a significantly lower velocity, small precipitates were observed. However, when the system was run at 0.13 mL/s, very large precipitates were observed in the flocculator (Figure 24).



**Figure 24:** At an effluent flow rate of 0.13 mL/s, flocculation was able to occur in the first redesign of the gravity powered system.

The implications of this result are the following:
The system must be run at a sufficiently low velocity that binding is able to occur but at a sufficiently high velocity that the number of collisions are maximized.

The system was sensitive to minute changes in the effluent velocity, indicating that there was a narrow optimal range with which the system was able to properly function.

#### Effects of Dosing of Polyaluminum Chloride
The ideal concentrations of PACl was thought to be modelled by the following Python program:
```python
import math as m
import numpy as np
from aguaclara.play import*

#Input the desired concentration of PACl through the system
Conc_PACl_exp = 40 * (u.milligram / u.liter)
#Input the desired upflow velocity in the sedimentation tube
upflow_velocity = 1.5 * (u.millimeter / u.second)

#Input your concentrations of your stock tanks
Conc_PACl_stock = 1000 * (u.milligram / u.liter)
Conc_fluoride_stock = 100 * (u.milligram / u.liter)

#Diameter of sedimentation tube
D_sed_tube = 1*u.inch
#Cross sectional area of sedimentation tube
Area_sed_tube = np.pi*(D_sed_tube**2)/4

#Calculate flow rate of system and input units of mL/s
Q_system = Area_sed_tube * upflow_velocity
Q_system.to(u.milliliter/u.second)
#Calculate the flow rate of PACl through the relation Q(PACl)*C(PACl)=Q(system)*C(system), where Conc_PACl_exp is the concentration of PACl in the system
Q_PACl = (Q_system * Conc_PACl_exp / Conc_PACl_stock).to(u.milliliter/u.second)
print(Q_PACl)

#Calculate the flow rate of fluoride through the relation Q(system)=Q(fluoride)+Q(PACl)
Q_fluoride = (Q_system-Q_PACl)
#Calculate the concentration of fluoride through the relation Q(system)*C(system)=Q(fluoride)*C(fluoride), where conc_fluoride_exp is concentration of fluoride in the system
conc_fluoride_exp = Conc_fluoride_stock * Q_fluoride / Q_system
print(conc_fluoride_exp)
```

In the second redesign of the experiment, this Python program was used to determine the ideal flow rate of PACl using an ideal concentration of PACl through the system, which was then mapped to the correct height using Figure 17. It was previously found that the ideal PACl concentration ranged from 10 mg/L to 50 mg/L; thus, the experiment was selected to run at a system concentration of 40 mg/L of PACl. The calculated flow rate of PACl that yielded this concentration was 0.034 mL/s, which corresponded to a height of 10cm (Figure 17). Under these conditions, it was found that an effluent flow rate of 0.48 mL/s yielded the largest flocs (Figure 25).



**Figure 25:** At an effluent flow rate of 0.48 mL/s and PACl flow rate of 0.034 mL/s, large flocs were observed in the flocculator of the second redesign of the system.

The system had thus far been unable to experience consistent flocculation despite using the height determined from the Python program.

It was first hypothesized that the system was unable to properly mix the red dye and PACl, preventing flocculation from occurring. However, after testing a variety of arrangements of the T-junction, including reverting it to old T-junction, and turning the T-junction vertically, it was found that flocculation was unable to occur in all of these arrangements.

It was then hypothesized that the system was deficient of PACl, and the microbore tubing was cut to decrease frictional headloss, allowing the PACl to enter at a high velocity. When testing against a variety of flow rates, flocculation still did not occur.

When the microbore tubing was made thinner, causing there to be more frictional headloss and thus a slower flow rate, the system was able to flocculate. Flocculation was observed at a PACl flow rate of 0.021 mL/s (8 cm) and an effluent flow rate of 0.68 mL/s (20 cm). After undergoing further testing, it was found that the system would flocculate under this same PACl flow rate at all effluent velocities. The effluent velocities dictated how large the observed flocs were, and it was found that an effluent flow rate of 0.51 mL/s to 0.75 mL/s (15 cm-25 cm) was most optimal.

This result suggested that dosing plays an essential role in the system’s ability to flocculate, and the necessary dose seemed to fall under a narrow range. The result likely deviated from the desired system concentration of PACl generated by the Python program because the length of the microbore tubing used in the Python analysis did not reflect that of the new system. Effluent velocity was important, but tended to govern the size of flocs rather than the existence of flocs. Further experiments should elucidate the relationship between the PACl dosage needed and the concentration of red dye (or fluoride) and whether the experimental results confirm the theoretical analysis done by the Python program.

### Improvement of Sedimentation Processes
#### Jar Testing
With the independently mixed solution, it was observed that the solution was first homogenous, but after some time, small particles similar to flocs were observed to form. When these flocs were allowed to settle, the majority of these flocs settled to the bottom, with only a small amount of flocs remaining on the surface of the water.

On the other hand, with the solution collected from the flocculator, it was observed that the majority of the flocs rose to the top of the solution rather than sinking (Figure 26).



**Figure 26:** The mechanics of the red dye was shown. The beaker on the left contained the solution acquired after flocculation and the beaker on the right contained the solution created through rapid stirring.

When both solutions were stirred once more with a magnetic stir bar, both solutions behaved in the same way. The majority of particles then settled, with a few floating to the top.

This seems to suggest that the flocculation process caused the water to act in a different manner than in normal mixing. It was hypothesized that a difference in pH may prevent mixing and the proper settling of flocs. However, when using pH strips that range between 1 and 14, the pH of both solutions were found to be approximately 8 (Figures 27 and 28).

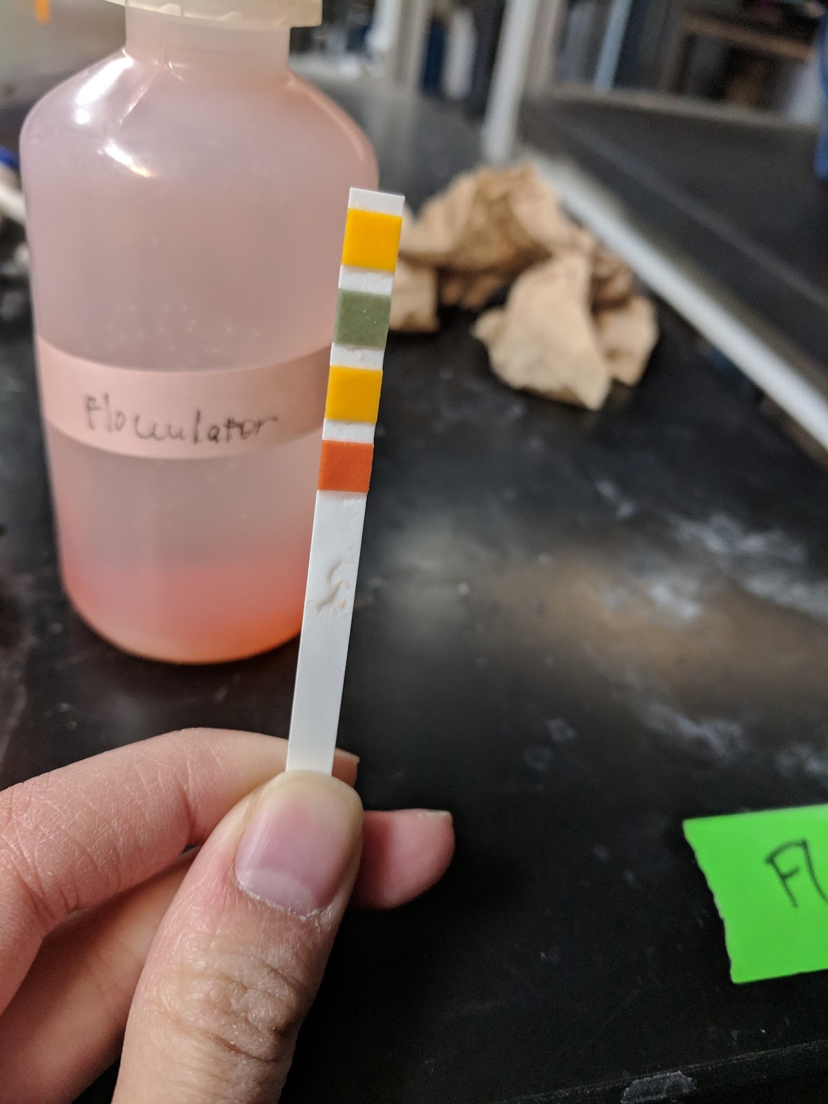
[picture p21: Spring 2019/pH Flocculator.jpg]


**Figure 27:** The pH of the solution collected from the flocculator sample was estimated to be 8 using a pH strip.

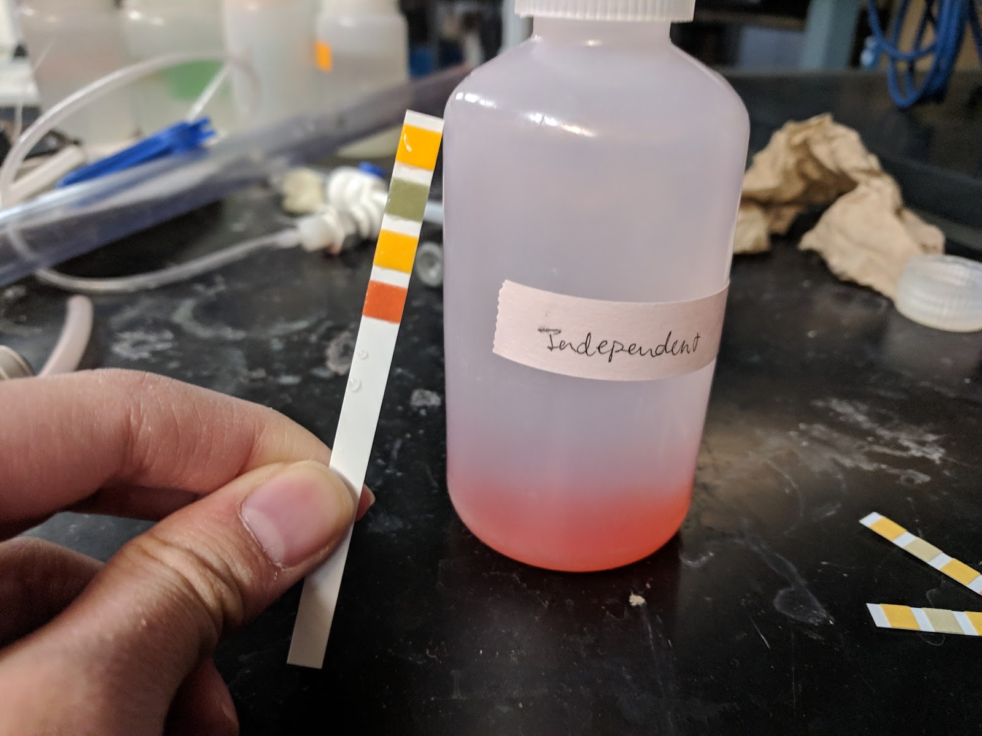
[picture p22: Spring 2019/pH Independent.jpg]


**Figure 28:** The pH of the independently mixed solution was also estimated to be 8 using a pH strip.

Both the independently mixed solution and solution collected from the flocculator had the same pH value, which ruled out the difference in pH potentially altering the mechanics of red dye, but the Fluoride Gravity team will verify this result using more sensitive pH strips or a pH meter.

When the apparatus was tested again with newly created red dye solution, the problem of small red dye flocs floating to the surface of the water in the sedimentation tube did not reoccur. This result seemed to be an anomaly.

#### Solving the Floating Floc Issue
As tests continued to be run on the system, it was noted that the red-dye flocs continued to float in the sedimentation tank, rather than settle. Despite the presence of the newly installed bottom geometry, this was continuing to occur.

The team had compiled multiple reasons for the observed phenomenon (as described earlier), for instance pH variations and dissolved solutes. However, the jar tests had clearly indicated that there was no variation in pH, nor did it appear that any contaminant solutes had made it into the solution.

After further analysis, it was hypothesized that the reason for the floating flocs could be dissolved gas. The source of this error/problem could be the usage of pressurized tap water that would result in the dissolution of air into the water. As a result, the flocs would be ‘pushed’ up through the water resulting in the “floating” behavior noted. This also seemed to explain why when the jars (from the jar test) were stirred, the flocs that were floating began to settle at the bottom. Some of the dissolved gas most likely escaped as stirring occurred, reducing the amount of gas and “floatation” of the flocs.

To solve this issue, the team began to utilize tap water that was filtered to remove any air from the water prior to using it in the system. The team immediately noticed that there were less flocs that were floating up the sedimentation tank, and a transition zone within the sedimentation tank was noticed. The flocs were sufficiently able to fall into the floc weir.

### Challenges
Over the course of the development and modification of the entire system, there are a couple of the challenges that the team is yet to overcome. Primarily, these fall under the following three categories:

* Flocculation
* Preventing air bubbles
* Scaling to fluoride

The first challenge is a rather recent one. Despite the team seeing tremendous success in flocculation early on in the testing phase, the system had no longer been flocculating at the same level as previously. While the team has some ideas as to why this is (potentially a disparity between using DI water and tap water or a difference in dosing that was unnoticed), it is still a challenge that needs to be overcome. Since the system’s success is predicated on the flocculation of the contaminant (e.g. red dye, fluoride), it is absolutely critical that the team - and future teams - work towards determining the reason for the sudden lack of flocculation.

Another issue that the team had constantly run into was the introduction of air within the system when flushing it, or even running the system. These air bubbles resulted in the significant slowing of the flow rate and reduced the mixing of the PACl and red dye in the flocculator and in the T-junction. Not only were these bubbles a potential source of error within the system and lack of flocculation, but removing these bubbles from the system was a time-consuming task. Thus, it is suggested that the team focuses on developing a system or methodology that can be effective in efficiently removing air bubbles.

Finally, a challenge with the system - in general - will be the scaling down of contaminant concentrations and the utilization of actual fluoride within the system. The primary concern was the system will not work effectively due to the incredibly small concentration of fluoride within the water. Especially given that consistent, large levels of flocculation were not occurring within a relatively high concentration of red dye (100 $\mu$L dye/400 mL of water), real-world (and significantly lower) concentrations of fluoride will surely not flocculate.

While the aforementioned challenges are significant in their difficulty, through multiple trials and modifications of the system, Fluoride Gravity could and will likely see success in the future.

## Future Work

The overarching goal of the Fluoride Gravity team is to determine the optimal method of removing fluoride from the water and creating the most compact system possible to be used for field testing. Future goals involve determine the dosages needed for optimal PACl binding at a variety of red dye, and eventually, fluoride concentrations, ensuring that flocculation is consistent every time the system is run, and testing the system's capacity to remove red dye at concentrations similar to natural concentrations of fluoride.

If flocculation is made consistent, efforts should move to creating an Onshape model for future deployment of the system in field testing.

## Conclusion

Proper mixing of PACl and red dye was necessary for flocculation and removal of fluoride, which was successfully visualized through the fabrication of a clear T-junction.

At too low of a flow rate of PACl entering the system, it was observed the precipitate formed was too small and the system velocity was too slow to have sufficient collisions for effective flocculation.

At too high of a flow rate of PACl entering the fluoride system, there were no precipitates formed and the effluent leaving the system contained both the PACl and red dye in solution.

The optimal flow rate of PACl entering the fluoride system was found in between the two extremes where the fluid is flowing at a high velocity to maximize collisions but not too high of a velocity such that the flocs break up. This velocity ranged from 0.45 mL/s to 0.76 mL/s, which corresponded to a change in height of the effluent line to be between 9.5 cm and 20 cm.

However, the system more highly depended on dosage. After the fabrication of the clear T-junction, the system was able to run at the PACl flow rate of 0.0206 mL/s.

After flocculation, the successful sedimentation of red dye experiments depended on the presence of a bottom geometry insert, but was able to form a fluidized bed after its addition.

The successes of the system imply that the reported system would be able to successfully remove fluoride from tap water. Once the experimental design is tested several times and able to be modeled optimally at all times, the design can be sent to communities with high concentrations of fluoride in their tap water for field testing and ultimately for water treatment to remove fluoride from drinking water systems.

## Bibliography
Akpan, P., Mehrabyan, T,. Sausele, D., & Zhang, V. (2018). Fluoride, Spring 2018. Retrieved from https://github.com/AguaClara/Fluoride-Auto/blob/master/FluorideReportSp18.md.

Bhattacharya, P., & Samal, A. (2018, April). Fluoride contamination in groundwater, soil and cultivated foodstuffs of
India and its associated health risks: A Review. Research Journal of Recent Sciences, 7(4),36-47. Retrieved from http://www.isca.in/rjrs/archive/v7/i4/6.ISCA-RJRS-2018-028.pdf.
Bureau of Indian Standards. (2012). IS 10500: Drinking water. Retrieved from https://archive.org/details/gov.in.is.10500.2012/page/n3.

EPA Method 9214. (1996, December). Retrieved from https://www.epa.gov/sites/production/files/2015-12/documents/9214.pdf.

Gebbie, P. (2001). Using Polyaluminium Coagulants in Water Treatment. Retrieved from http://wioa.org.au/conference_papers/2001/pdf/paper6.pdf.

Herrboldt, J. P. (2016). Fluoride, Natural Organic Matter, and Particles: The Effect of Ligand Competition on the Size Distribution of Aluminum Precipitates in Flocculation. Retrieved from https://repositories.lib.utexas.edu/bitstream/handle/2152/39194/HERRBOLDT-THESIS-2016.pdf?sequence=1.

Kowalchuk, E. E. (2011). Selective Fluoride Removal by Aluminum Precipitation and Membrane Filtration. Retrieved from https://digitalrepository.unm.edu/cgi/viewcontent.cgi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.

LeChevallier, M. W., & Au, K. (2014, December 10). Water treatment and pathogen control: Process efficiency in achieving safe drinking water. Retrieved from https://www.who.int/water_sanitation_health/publications/9241562552/en/.

Longo, A., Desai, D., & Dao, K. (2016). Fluoride Floc Blanket, Spring 2016. Retrieved from https://drive.google.com/file/d/0B9yahrdDmfVpQ0t0M2NUUkRRNHM/view.

Pang, C., Sarmiento, K., & Tsang, C. (2018). Fluoride Gravity, Fall 2018. Retrieved from https://github.com/AguaClara/Fluoride_Gravity/blob/master/Fall%202018/Fluoride_Grav_Fall2018_Report.md.

Parthasarathy, N., Buffle, J., & Haerdi, W. (1986). Study of interaction of polymeric aluminium hydroxide with fluoride. Canadian Journal of Chemistry, 64(1), 24-29. doi:10.1139/v86-006.

United States, NYC Environmental Protection. (2016). New York City 2016 Drinking Water Supply and Quality Report. New York. Retrieved from http://www.nyc.gov/html/dep/pdf/wsstate16.pdf.

World Health Organization. (2016, August 29). Water-related diseases. Retrieved from http://www.who.int/water_sanitation_health/diseases-risks/diseases/fluorosis/en/.

## Manual

## Experimental Setup
### Set-up
Step 1. Preparing stock solutions
* PACL: dilute PACl stock to yield 2 L of 1000 mg/mL PACl solution
* Red dye: use the dilution factor 100 $\mu$L of Red Dye 40 in 400 mL of water.

Step 2. Filling stock tanks and constant head tanks
* PACl: fill constant head tank with the prepared PACl stock solution until the volume is a small distance below the bottom of the float valve. Use the remainder of the solution to fill the PACl stock tank
* Red dye: fill the fluoride stock tank with red dye. Open the valve and let the constant head tank fill.

Step 3: Filling the flocculator
* Connect a tube from the sink faucet to the flocculator.
* Ensure that the valve to the right of the T junction is closed to prevent backflowing.
* Turn on the sink faucet and let the system fill with water until bubbles do not run through the sedimentation tube.
* Quickly connect the flocculator back to the T-junction, making sure as little air as possible enters the system.

Step 4. Starting the system
* Open the valve to the right of the T junction. Water should be able to flow through the effluent line. If water is unable to flow, connect the flocculator to a tube connected to the sink faucet, and run water through the system until bubbles do not persist.
* After system begins to flow, open the valve below the PACl constant head tank. Shine a flashlight through the tube connected to the T-junction to ensure that PACl is dripping. If the PACl solution does not flow, flick the tube until the flow starts.
* Open the waste line until the flow is slightly slower than the flow out of the effluent line.

### Stopping the System
Step 1. Closing valves
* Ensure that all valves are closed.

Step 2. Adjusting effluent line
* Move effluent line up until it is above the volume level of the fluoride constant head tank.

### Cleaning the System
Step 1. Disconnecting system
* Disconnect the tube below the valve of the PACl constant head tank. Plug the flocculator with a stopper. Open the valve and allow the PACl solution to drain.
* Disconnect the tube connecting the fluoride constant head tank to the fluoride stock tank. Empty the fluoride constant head tank and fluoride stock tank.

Step 2. Cleaning flocculator
* Open the waste line.
* Run water through the system until all flocs have been removed.

## Python Code
### Code for Figure 3: Experimental Data Fit with Langmuir Adsorption Model
Below is the code used to visualize the fit of the Langmuir adsorption model with the experimental data found by the Fluoride Auto team.
```Python
import pandas as pd
import matplotlib.pyplot as plt

#import experimental data as a CSV file
df = pd.read_csv ('https://raw.githubusercontent.com/AguaClara/Fluoride_Gravity/master/Spring%202019/Langmuir%20Isotherm%202.csv')
#import Langmuir best fit line as a CSV file
df1 = pd.read_csv ('https://raw.githubusercontent.com/AguaClara/Fluoride_Gravity/master/Spring%202019/Langmuir%20Best%20Fit.csv')

#save each column of data
effluent=pd.to_numeric(df["Effluent Concentration (mmol/g)"])
uptake=pd.to_numeric(df["Uptake (mmol/g)"])
Lx=pd.to_numeric(df1["Lx"])
Ly=pd.to_numeric(df1["Ly"])

#plot the experimental data and the Langmuir isotherm
plt.plot(effluent,uptake,'o', label='Experimental Data')
plt.plot(Lx,Ly, label='Langmuir Best Fit')

#formatting
plt.xlabel('Effluent Concentration (mmol/g)')
plt.ylabel('Uptake (mmol/g)')
plt.title('Experimental Data Fit with Langmuir Adsorption Model')
plt.minorticks_on()
plt.grid(which = 'major')
plt.grid(which = 'minor')

plt.legend()

plt.show()
```

### Code for Figure 16: Gravimetric Determination of PACl Flow Rate
Below is the code used to describe the relationship between the change in height of the PACl constant head tank and the PACl flow rate, determined gravimetrically using a mass balance.
```Python
#Gravimetrically Determined Average Flow Rate of PACl vs. Height
#First redesign of system (microbore tubing dripping PACl directly into fluoride constant head tank)

import matplotlib.pyplot as plt
import numpy as np
from scipy import stats

#Change in height of PACl system
height=[5,10,15,20]
#System flow rate measured from effluent
flowrate=[0.00344,0.00894,0.0125,0.01542]

#Plot data points from experiment
plt.plot(height,flowrate,'o')

#Formatting plot
plt.xlabel('Height (cm)')
plt.ylabel('Flow Rate (mL/s)')
plt.title('Gravimetrically Determined Average Flow Rate of PACl')
plt.minorticks_on()
plt.grid(which = 'major')
plt.grid(which = 'minor')

#Calculate linear regression and store stats in variables
linreg=stats.linregress(height,flowrate)
slope,intercept,r_value=linreg[0:3]

#Plot linear regression and legend
xvals=np.arange(0,25,0.01)
yvals=slope*xvals+intercept
plt.plot(xvals,yvals,color='blue',label='y={:.6f}x+{:.6f}\nR\N{SUPERSCRIPT TWO}={:.4f}'.format(slope,intercept,r_value**2))
plt.legend()

plt.show()
```
### Code for Figure 17: Volumetric Determination of PACl Flow Rate
Below is the code used to describe the relationship between the change in height of the PACl constant head tank and the PACl flow rate, determined volumetrically by measuring the time to fill a graduated cylinder to 10 mL.
```Python
#Volumetric Determined Average Flow Rate of PACl vs. Height
#Second redesign of system (microbore tubing dripping into T system)

import matplotlib.pyplot as plt
import numpy as np
from scipy import stats

#Change in height of PACl system
height=[5,10,15,20,25,30]
#System flow rate measured from effluent
flowrate=[0.02583472335,0.03367053161,0.03962373578,0.04338574177,0.05256246053,0.05848966854]

#Plot data points from experiment
plt.plot(height,flowrate,'o')

#Formatting plot
plt.xlabel('Height (cm)')
plt.ylabel('Flow Rate (mL/s)')
plt.title('Volumetrically Determined Average Flow Rate of PACl')
plt.minorticks_on()
plt.grid(which = 'major')
plt.grid(which = 'minor')

#Calculate linear regression and store stats in variables
linreg=stats.linregress(height,flowrate)
slope,intercept,r_value=linreg[0:3]

#Plot linear regression and legend
xvals=np.arange(0,35,0.01)
yvals=slope*xvals+intercept
plt.plot(xvals,yvals,color='blue',label='y={:.6f}x+{:.6f}\nR\N{SUPERSCRIPT TWO}={:.4f}'.format(slope,intercept,r_value**2))
plt.legend()

plt.show()
```

### Code for Figure 18: Volumetric Determination of PACl Flow Rate of Revised System with Vertical T-junction
Below is the code used to describe the relationship between the change in height of the PACl constant head tank and the PACl flow rate with the redesign of the system with a vertical T-junction and elongated microbore tubing. The flow rate of PACl entering the system was determined volumetrically by measuring the time to fill a graduated cylinder to 10 mL.

```Python
#Volumetric Determined Average Flow Rate of PACl vs. Height
#Vertical T-Junction redesign of system (microbore tubing dripping into T system)

import matplotlib.pyplot as plt
import numpy as np
from scipy import stats

#Change in height of PACl system
height=[10,15,20,25]
#System flow rate measured from effluent
flowrate=[0.01559184396,0.0188905051,0.02100172006,0.02395553165]

#Plot data points from experiment
plt.plot(height,flowrate,'o')

#Formatting plot
plt.xlabel('Height (cm)')
plt.ylabel('Flow Rate (mL/s)')
plt.title('Volumetrically Determined Average Flow Rate of PACl')
plt.minorticks_on()
plt.grid(which = 'major')
plt.grid(which = 'minor')

#Calculate linear regression and store stats in variables
linreg=stats.linregress(height,flowrate)
slope,intercept,r_value=linreg[0:3]

#Plot linear regression and legend
xvals=np.arange(0,35,0.01)
yvals=slope*xvals+intercept
plt.plot(xvals,yvals,color='blue',label='y={:.6f}x+{:.6f}\nR\N{SUPERSCRIPT TWO}={:.4f}'.format(slope,intercept,r_value**2))
plt.legend()

plt.show()

```

## Code for Figure 21: Determination of Effluent Flow Rate
Below is the code used to describe the relationship between the change in height of the effluent tube from the point of zero flow and the effluent flow rate. The effluent flow rate was determined volumetrically by measuring the time to fill a graduated cylinder to 10 mL.
```Python
#Effluent Flow Rate vs. Height
#Second redesign of system

import matplotlib.pyplot as plt
import numpy as np
from scipy import stats

#Change in height of the effluent tube from the point of zero flow
height=[5,10,15,20,25,30,35,40]
#System flow rate measured from effluent line
flowrate=[0.303921123,0.4525731793,0.6403088421,0.7827710055,0.8833781973,1.043483972,1.186551281,1.336794586]

#Plot data points from experiment
plt.plot(height,flowrate,'o')

#Formatting plot
plt.xlabel('Change in Height (cm)')
plt.ylabel('Flow Rate (mL/s)')
plt.title('Effluent Flow Rate of System')
plt.minorticks_on()
plt.grid(which = 'major')
plt.grid(which = 'minor')

#Calculate linear regression and store stats in variables
linreg=stats.linregress(height,flowrate)
slope,intercept,r_value=linreg[0:3]

#Plot linear regression and legend
xvals=np.arange(0,45,0.01)
yvals=slope*xvals+intercept
plt.plot(xvals,yvals,color='blue',label='y={:.6f}x+{:.6f}\nR\N{SUPERSCRIPT TWO}={:.4f}'.format(slope,intercept,r_value**2))
plt.legend()

plt.show()
```
## Code for Figure 22: Redetermination of Effluent Flow Rate for Horizontal Clear T-Junction System
Below is the code used to describe the relationship between the change in height of the effluent tube from the point of zero flow and the effluent flow rate of the system with the horizontal clear T-junction set up. The effluent flow rate was determined volumetrically by measuring the time to fill a graduated cylinder to 10 mL.
```Python
#New Effluent Flow Rate vs. Height
#Horizontal Clear T-junction redesign of system

import matplotlib.pyplot as plt
import numpy as np
from scipy import stats

#Change in height of the effluent tube from the point of zero flow
height=[5,10,15,20,25]
#System flow rate measured from effluent line
flowrate=[0.1870908477,0.4071835715,0.5584123322,0.6901425418,0.8296203472]

#Plot data points from experiment
plt.plot(height,flowrate,'o')

#Formatting plot
plt.xlabel('Change in Height (cm)')
plt.ylabel('Flow Rate (mL/s)')
plt.title('Effluent Flow Rate of System')
plt.minorticks_on()
plt.grid(which = 'major')
plt.grid(which = 'minor')

#Calculate linear regression and store stats in variables
linreg=stats.linregress(height,flowrate)
slope,intercept,r_value=linreg[0:3]

#Plot linear regression and legend
xvals=np.arange(0,45,0.01)
yvals=slope*xvals+intercept
plt.plot(xvals,yvals,color='blue',label='y={:.6f}x+{:.6f}\nR\N{SUPERSCRIPT TWO}={:.4f}'.format(slope,intercept,r_value**2))
plt.legend()

plt.show()
```

## Code for Figure 23: Redetermination of Effluent Flow Rate for Vertical Clear T-Junction System
Below is the code used to describe the relationship between the change in height of the effluent tube from the point of zero flow and the effluent flow rate of the system with the vertical clear T-junction set up. The effluent flow rate was determined volumetrically by measuring the time to fill a graduated cylinder to 10 mL.

```Python

#Effluent Flow Rate vs. Height
#Vertical T-junction redesign of system

import matplotlib.pyplot as plt
import numpy as np
from scipy import stats

#Change in height of the effluent tube from the point of zero flow
height=[10,15,20,25,30,35,40]
#System flow rate measured from effluent line
flowrate=[0.3493666354,0.5100734246,0.6434089442,0.7517197384,0.9259788526,1.069752319,1.225014697]

#Plot data points from experiment
plt.plot(height,flowrate,'o')

#Formatting plot
plt.xlabel('Change in Height (cm)')
plt.ylabel('Flow Rate (mL/s)')
plt.title('Effluent Flow Rate of System')
plt.minorticks_on()
plt.grid(which = 'major')
plt.grid(which = 'minor')

#Calculate linear regression and store stats in variables
linreg=stats.linregress(height,flowrate)
slope,intercept,r_value=linreg[0:3]

#Plot linear regression and legend
xvals=np.arange(0,45,0.01)
yvals=slope*xvals+intercept
plt.plot(xvals,yvals,color='blue',label='y={:.6f}x+{:.6f}\nR\N{SUPERSCRIPT TWO}={:.4f}'.format(slope,intercept,r_value**2))
plt.legend()

plt.show()

```

## Determination of Height Needed for Desired System Concentration of PACl
Below is the code used to determine the flow rate of PACl needed for a desired system concentration of PACl and upflow velocity through the sedimentation tube.
```python
import math as m
import numpy as np
from aguaclara.play import*

#Input the desired concentration of PACl through the system
Conc_PACl_exp = 40 * (u.milligram / u.liter)
#Input the desired upflow velocity in the sedimentation tube
upflow_velocity = 1.5 * (u.millimeter / u.second)

#Input your concentrations of your stock tanks
Conc_PACl_stock = 1000 * (u.milligram / u.liter)
Conc_fluoride_stock = 100 * (u.milligram / u.liter)

#Diameter of sedimentation tube
D_sed_tube = 1*u.inch
#Cross sectional area of sedimentation tube
Area_sed_tube = np.pi*(D_sed_tube**2)/4

#Calculate flow rate of system and input units of mL/s
Q_system = Area_sed_tube * upflow_velocity
Q_system.to(u.milliliter/u.second)
#Calculate the flow rate of PACl through the relation Q(PACl)*C(PACl)=Q(system)*C(system), where Conc_PACl_exp is the concentration of PACl in the system
Q_PACl = (Q_system * Conc_PACl_exp / Conc_PACl_stock).to(u.milliliter/u.second)
print(Q_PACl)

#Calculate the flow rate of fluoride through the relation Q(system)=Q(fluoride)+Q(PACl)
Q_fluoride = (Q_system-Q_PACl)
#Calculate the concentration of fluoride through the relation Q(system)*C(system)=Q(fluoride)*C(fluoride), where conc_fluoride_exp is concentration of fluoride in the system
conc_fluoride_exp = Conc_fluoride_stock * Q_fluoride / Q_system
print(conc_fluoride_exp)
```
Output: Flow rate of PACl is 0.0304 mL/s for a PACL system concentration of 40 mg/L and an upflow velocity of 1.5 mm/s. By using the regression in Figure 16, it was determined that the height of PACl should be 11 cm.

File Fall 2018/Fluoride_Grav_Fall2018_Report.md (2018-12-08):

# Fluoride Gravity, Fall 2018
#### Ching Pang, Kevin Sarmiento, Cheer Tsang

#### December 8, 2018
This publication Fluoride, Fall 2018 was developed under Assistance Agreement No. SU-83695001 awarded by the U.S. Environmental Protection Agency to Cornell University. It has not been formally reviewed by EPA. The views expressed in this document are solely those of Ching Pang, Kevin Sarmiento, and Cheer Tsang and do not necessarily reflect those of the Agency. EPA does not endorse any products or commercial services mentioned in this publication.
 ## Index
<!-- START doctoc generated TOC please keep comment here to allow auto update -->
<!-- DON'T EDIT THIS SECTION, INSTEAD RE-RUN doctoc TO UPDATE -->
**Table of Contents**  *generated with [DocToc](https://github.com/thlorenz/doctoc)*
- [Abstract](#abstract)
- [Introduction](#introduction)
- [Literature Review](#literature-review)
- [Previous Work](#previous-work)
- [Methods](#methods)
  - [Experimental Apparatus](#experimental-apparatus)
  - [Head Loss Calculations](#head-loss-calculations)
    - [System Flow Rate](#system-flow-rate)
    - [Coagulant Flow Rate](#coagulant-flow-rate)
    - [Python Code](#python-code)
  - [Measuring Coagulant Flow Rate](#measuring-coagulant-flow-rate)
    - [Balance](#balance)
    - [IV Drip System](#iv-drip-system)
- [Results](#results)
  - [Calculating Stock Concentrations](#calculating-stock-concentrations)
    - [PACl Stock Concentration](#pacl-stock-concentration)
  - [Sedimentation Tube Bottom Geometry](sedimentation-tube-bottom-geometry)
- [Future Work](#future-work)
- [Conclusion](#conclusion)
- [Bibliography](#bibliography)
- [Manual](#manual)
  - [Fabrication Details](#fabrication-details)
    - [Frame](#frame)
    - [Stock Tanks](#stock-tanks)
      - [PACl Tank Platforms](#pacl-tank-platforms)
      - [Fluoride Tank Platforms](#fluoride-tank-platforms)
    - [Tubing](#tubing)
    - [Flocculator](#flocculator)
    - [Reactor](#reactor)
  - [Special Components](#special-components)
    - [Adjustable Sliders](#adjustable-sliders)
    - [IV Drip Chamber](#iv-drip-chamber)
  -[Operation Manual](#operation-manual)
    - [Initial Set-up](#initial-set-up)
    - [Cleaning Procedure](#cleaning-procedure)
  - [Experimental Checklist](#experimental-checklist)
<!-- END doctoc generated TOC please keep comment here to allow auto update -->

## Abstract

Fluoride contamination of drinking water is a common public health issue in some regions of the world such as India. The fluoride teams' overarching goal is to create low cost, compact, and sustainable solutions to fluoride contamination in drinking water. The Fall 2018 Fluoride Gravity team aims to simplify the design of a gravity powered fluoride removal research apparatus that would allow current and future research teams to easily conduct fluoride removal experiments in the field. Experiments conducted with this research apparatus will be used to determine the on-site feasibility of the proposed fluoride removal method.  

## Introduction

The expansion of AguaClara Cornell technology to new places around the world, like India, has uncovered new challenges and prompted new goals. The bulk of the AguaClara plants that have been constructed to date are located in Central America where surface waters, such as rivers and lakes, are a major source of water for AguaClara purification plants.

In contrast to Central America, 85% of the Indian population obtains their drinking water from groundwater sources such a wells and aquifers ([World Bank, 2017](http://www.worldbank.org/en/news/feature/2012/03/06/india-groundwater-critical-diminishing)). Compared to surface water, groundwater has a much lower turbidity due to natural filtration processes, which use the soil and underlying rock material to filter particulate matter from water. While this process is capable of removing undissolved particulate matter and pathogenic microorganisms, it allows minerals and metals to leach from the surrounding geological landscape into the groundwater. The types of contaminants seen in the water of one region depend heavily on the types of parent rock material and soils found in that region. Therefore, there is a lot of variability between regions in terms of contamination of groundwater with agents such as fluoride.

India, located on one of the Fluoride Belts, have expanses of land that are geologically rich in fluoride, and therefore have a much greater capacity to leach fluoride into groundwater [(Water-related diseases, 2016)](http://www.who.int/water_sanitation_health/diseases-risks/diseases/fluorosis/en/). India contains about 14% of the total fluoride deposited on the earth's crust  [(Mondal, Dutta, & Gupta, 2016)](https://doi.org/10.1007/s10653-015-9743-7). The coupling of high groundwater fluoride concentrations with a high population dependency on groundwater for consumptions has produced a serious public health problem that needs to be addressed.

In contrast to Central America, 85% of the Indian population obtains their drinking water from groundwater sources such a wells and aquifers ([World Bank, 2017](http://www.worldbank.org/en/news/feature/2012/03/06/india-groundwater-critical-diminishing)). Compared to surface water, groundwater has a much lower turbidity due to natural filtration processes, which use the soil and underlying rock material to filter particulate matter from water. While this process is capable of removing undissolved particulate matter and pathogenic microorganisms, it allows minerals and metals to leach from the surrounding geological landscape into the groundwater.

Fluoride has become a common additive to municipal water systems in places such as the United States, where there is little to no fluoride naturally present in the water. [(NYC DEP, 2016)](http://www.nyc.gov/html/dep/pdf/wsstate16.pdf) There are, however, a number of health risks associated with the consumption of fluoride at higher concentrations. The World Health Organization has an absolute upper limit on the concentration of fluoride in drinking water of 1.5 $\mathrm{\frac{mg}{L}}$ to minimize the negative impacts of elevated fluoride on human health. Dental fluorosis, the mildest condition caused by the overconsumption, occurs at fluoride concentrations above 0.9 $\mathrm{\frac{mg}{L}}$. Skeletal fluorosis can begin to develop at fluoride concentrations above 3 $\mathrm{\frac{mg}{L}}$, and crippling skeletal fluorosis can occur at concentrations above 10 $\mathrm{\frac{mg}{L}}$ [(WHO, 2004)](http://www.who.int/water_sanitation_health/dwq/chemicals/fluoride.pdf). The number of cases of dental fluorosis has been shown to range from 13-91 percent of the total population across India [(Arlappa et al., 2013)](http://www.ijrdh.com/files/11.Fluorosis.pdf). In total, it is estimated that 66 million people in India are consuming fluoride contaminated water [(Arlappa et al., 2013)](http://www.ijrdh.com/files/11.Fluorosis.pdf). While there is no established mean fluoride concentration in Indian groundwater, concentrations in some extreme cases have been measured as high as 20 $\mathrm{\frac{mg}{L}}$ in some regions, but most frequently are below 5 $\mathrm{\frac{mg}{L}}$ [(LeChevallier and Au, 2004)](http://www.who.int/water_sanitation_health/publications/9241562552/en/).

The Bureau of Indian Standards has created water quality standards designed to protect the public from the adverse effects of fluoride, with the upper limit for fluoride at 1 $\mathrm{\frac{mg}{L}}$, and the permissible limit in the absence of an alternate source at 1.5 $\mathrm{\frac{mg}{L}}$ [(Bureau of Indian Standards, 2012)](http://archive.org/details/gov.in.is.10500.2012). AguaClara aims to match the standards set by the Bureau of Indian Standards, and therefore strives to achieve an effluent fluoride concentration of 1 $\mathrm{\frac{mg}{L}}$ or lower. The team will be experimenting with stock fluoride concentrations up to 20 $\mathrm{\frac{mg}{L}}$ in order to simulate the highest concentrations these filtration systems may encounter out in the field.

Fluoride Gravity team's primary objective was to modify and test the gravity-powered fluoride removal apparatus. The goal was to make it easy to adjust and control key variables such as flow rate, PACl concentration, and fluoride concentration. The gravity-powered apparatus will then be used to conduct feasibility analyses on site, which will determine if the proposed system of fluoride removal is a viable solution in the intended setting. If these tests are successful, AguaClara can begin designing a marketable product that can used by communities in India.

## Literature Review

### Interactions Between Fluoride, Natural Organic Matter (NOM), and Polyaluminum Chloride (PACl)

The dynamic interactions between fluoride, Natural Organic Matter (NOM), and the aluminum based coagulants used in traditional drinking water treatment processes are important to consider when treating water sources containing significant amounts of NOM and fluoride. While many of the sources of water in India come from wells, and therefore the NOM content is generally low, interactions between these three types particles have not been vastly studied. The presence of fluoride reduced the capacity of water treatment systems to remove other contaminants such as turbidity and NOM due to fluoride's capacity to inhibit aluminum hydroxide precipitation [(Herrboldt, 2016)]((https://repositories.lib.utexas.edu/bitstream/handle/2152/39194/HERRBOLDT-THESIS-2016.pdf?sequence=1)). In the presence of fluoride, aluminum precipitates become smaller in size compared to precipitates created in fluoride-free solutions. Water with fluoride produced more particles with diameters smaller than 10&mu;m. Smaller particles are more difficult to remove during the sedimentation process. Tests with both NOM and fluoride also showed similar effects with smaller floc sizes, adding to the difficulty of treatment.

### Effect of pH on Fluoride Removal

The difficulty of fluoride removal is also affected by environmental factors. At a pH value below 5, nearly all the fluoride present in fluoride and aluminum based coagulant solution are in the form of a fluoro-aluminum complexation (Gong et al. 2012 in [Herrboldt, 2016](https://repositories.lib.utexas.edu/bitstream/handle/2152/39194/HERRBOLDT-THESIS-2016.pdf?sequence=1)). Such complexation is soluble in water and cannot be removed by coagulation which therefore makes fluoride removal by traditional methods at pH values below 5 unlikely. However, at pH values greater than 8 nearly all fluoride exists freely as fluoride ion, allowing the formation of flocs to occur. While parameters, such as pH can be carefully controlled in the lab, it varies can vary depending on local geology and other chemical factors out in the field. Further research about the expected chemistry of groundwater in regions like India would help the team's overall understanding. For example, if pH is rarely observed to be 5 in groundwater then the effect of pH would also be minimal. Fluoride removal was observed to occur best in a coagulation treatment process when the molar ratio between hydroxide and fluoride was greater than 2.4 [OH<sup>-</sup>]:[F<sup>-</sup>] (Hu et al., 2005).

### Fluoro-aluminium Complexation

The formation of a fluoro-aluminum complex is also responsible for an observed increase in residual aluminum concentration [(Herrboldt, 2016)]((https://repositories.lib.utexas.edu/bitstream/handle/2152/39194/HERRBOLDT-THESIS-2016.pdf?sequence=1)). Formation of aluminum hydroxide is negatively affected by the presence of fluoro-aluminum, which prevents the formation of larger diameter particles. This reduces the system's capacity to remove both fluoride and residual aluminum. When comparing experiments that contained aluminum coagulant and NOM mixtures with aluminum coagulant and fluoride mixtures, both of which contained aluminum concentration of 8.0 $\mathrm{\frac{mg}{L}}$, the amount of residual aluminum was found to be 0.058 $\mathrm{\frac{mg}{L}}$ and 0.244 $\mathrm{\frac{mg}{L}}$ respectively. Thus, residual aluminum concentration increased by nearly an order of magnitude when fluoride was present. Unintended residual aluminum release in the effluent water supply from systems can be a concern if fluoride is present in the water.

### Collection and Analysis of Fluoride Samples
In order to measure the fluoride concentration, an Ion-Selective Electrode (ISE) fluoride probe is often used. One of the biggest issues in previous semesters was the inaccuracy of measurements taken by the fluoride probe. In order to mitigate these errors, the following quality-control procedures should be followed.

There are three main critical interferences that can impact the accuracy of the fluoride probe. The first is the presence of polyvalent cations such as Fe<sup>+3</sup> and Al<sup>+3</sup> which form complexes with F<sup>-</sup>. ISE fluoride probes can only detect solubilized fluoride and therefore would give inaccurate fluoride readings when in the presence of Fe<sup>+3</sup> and Al<sup>+3</sup>, as is the case when Polyaluminum Chloride (PACl) coagulant is added to the system. To account for this interference, Total Ionic Strength Adjuster Buffer (TISAB) solution is added to samples to solubilize the fluoride in the sample. The use of TISAB is also critical in remedying a second source of interference, pH. TISAB is a buffer that keeps the sample at a constant pH of about 5-5.5 to avoid ISE probe interference from hydroxide at high pH and bifluoride formation, undetectable to ISE probe, at lower pH. Lastly, the temperature of the samples can also be a significant source of error in fluoride measurements. In order to collect accurate data, samples should not deviate more than $\pm 1^\circ$C from those used to create the standard curve or from each other ([EPA Method 9214](https://www.epa.gov/sites/production/files/2015-12/documents/9214.pdf)).

Several quality control measures should be taken into consideration, such as the use of containers. The first is the highly recommended use of polyethylene plastic over glassware, as fluoride can adsorb to glass, which may result in inaccurate readings. Another quality control measure is the use of an Initial Calibration Verification (ICV) standard and a Continuing Calibration Verification (CCV) standard. These would consist of a solution of known fluoride concentration within the mean expected fluoride concentration that is being tested. The ICV would be utilized as a way to test the accuracy of the calibration curve prior to the analysis of unknown samples. Similarly, The CCV would be used after every 10 samples as a way to check that the fluoride probe has not drifted significantly from the standard curve. Both ICV and CCV controls should be within 10% of their known values. A final quality control measure that is suggested is the use of a blank after each ICV and CCV. The control blank would contain 1 part water and 1 part TISAB to ensure that the fluoride probe was not contaminated in some way with residual fluoride. Implementing these methods can possibly enhance the accuracy of data in future experiments.

## Previous Work

A coagulant-sedimentation process was used to remove fluoride. A series of bench experiments were conducted using polyalumnum chloride (PACl) as the coagulant and by varying concentrations of fluoride.

The Spring 2016 team conducted bench tests using clay and PACl, and were able to successfully create a floc blanket. After adding in fluoride, their system was able to remove 85% of the initial fluoride ([Longo, 2016](https://drive.google.com/file/d/0B9yahrdDmfVpQ0t0M2NUUkRRNHM/view)). The Summer 2017 team determined that the addition of clay was unnecessary, since it caused an increase in effluent turbidity ([Akpan et al., 2017](https://github.com/AguaClara/Fluoride-Auto/blob/master/FluorideReportSp18.md)). Thus, the Fall 2017 team ran experiments with only fluoride and PACl, without the addition of clay. They determined that their reactors would fail after 10 hours due to sludge buildup in the reactor. After switching to a new reactor geometry designed by the High Rate Sedimentation 2017 Summer Team, the time to failure increased, allowing for higher upflow velocities. Thus, the Fall 2017 team determined that an upflow velocity of 1.5 mm/s was optimal for preventing sludge buildup in the reactor. The team then ran experiments with various PACl concentrations to create an adsorption model, which would allow users to determine an optimal PACl dosage for the influent fluoride concentration.

The Spring 2018 team began constructing a gravity-powered apparatus for fluoride removal ([Akpan et. al, 2018](https://github.com/AguaClara/Fluoride-Auto/blob/master/FluorideReportSp18.md)).

gravity_schematic

**Figure 1:** Schematic for gravity-powered apparatus. The height difference between the effluent of the sedimentation tank and the fluoride constant head tank (h2) determined the flow rate through the system.

The principle behind the design is that the difference in head between the surface of the constant head tank of the influent and the effluent supplies enough potential energy to cause flow through the system. Float valves in the constant head tanks for fluoride and PACl were utilized to keep the water level and thus, the flow, constant throughout the system. The PACl concentration in the coagulant stock tank is fixed. Therefore, the concentration of coagulant into the system is determined by its flow rate. In order to change the PACl concentration throughout the system to accommodate for varying system flow rates, the PACl flow rate is adjusted accordingly.

The Summer 2018 team modified the gravity-powered apparatus fabricated by the Spring 2018 team. Adjustable sliders were added to allow for easy height adjustments of the sedimentation tube, coagulant stock tank, and coagulant constant head tank, and thus adjusting the flow rate of the system (Figure 1).

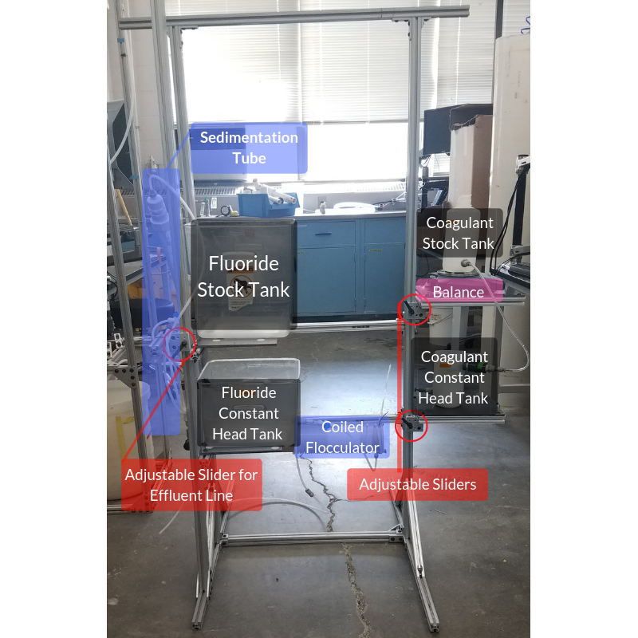
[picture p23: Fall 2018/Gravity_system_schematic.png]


**Figure 2:** Modified gravity powered reactor shown with 3 adjustable sliders.

The Summer 2018 team also ran a series of bench experiments with varying concentrations of fluoride and PACl to create an adsorption model. Fluoride concentrations ranging from 3 to 20 mg/L and PACl concentrations of 10 to 50 mg/L were tested. Experiments were run on the bench setup utilized by previous semesters (Figure 2).



**Figure 3:** Schematic for bench system.

An adsorption model was created using the data from Summer 2018 by the [Fall 2018 Fluoride Auto team](https://github.com/AguaClara/Fluoride-Auto). The effluent concentration of fluoride in mmol/L was plotted against the fluoride uptake (amount adsorbed) in mmol/g. Data points at 1.5 hr were selected from each experiment, at each fluoride and PACl concentration tested.

A Langmuir Isotherm was then fitted to the data, using the following equation:

$$ \frac{C_e}{q_e} = \frac{1}{q_e}C_e+\frac{1}{K_L\cdot q_m} $$

where $C_e$ is the equilibrium concentration of the adsorbant, $q_e$ is the amount adsorbed at equilibrium, and $K_L$ and $q_m$ are Langmuir constants which are related to adsorption capacity and energy of adsorption.

An R-squared value of 0.7611 was observed, indicating a relatively accurate fit of the Langmuir adsorption model and the experimental data. For more information on the adsorption model, see the [2018 Fluoride Auto Final Report](https://github.com/AguaClara/Fluoride-Auto/blob/master/Fall%202018/Automated%20System/Fall_2018_Report.md).

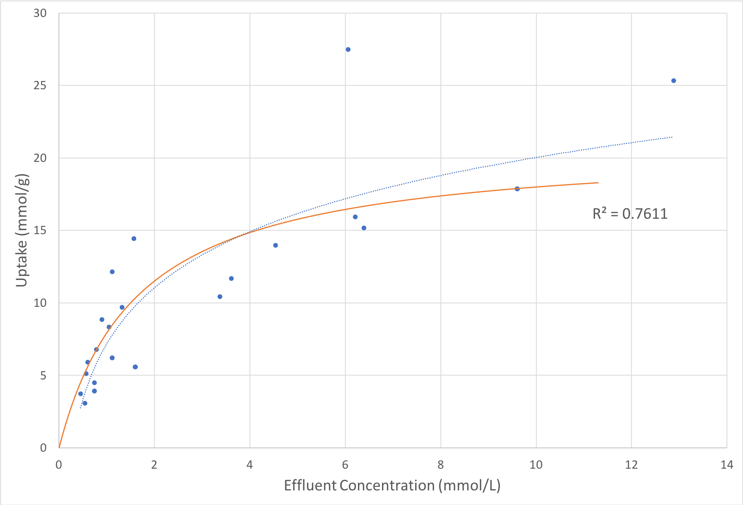
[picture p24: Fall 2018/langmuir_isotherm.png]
langmuir


**Figure 4:** Langmuir isotherm fitted to experimental data from Summer 2018. Model created by [Spring 2018 Fluoride Auto team](https://github.com/AguaClara/Fluoride-Auto/blob/master/Fall%202018/Automated%20System/Fall_2018_Report.md).

In Fall 2018, two fluoride teams were created: [Fluoride Auto](https://github.com/AguaClara/Fluoride-Auto) focused on creating an adsorption model by running bench experiments, and [Fluoride Gravity](https://github.com/AguaClara/Fluoride_Gravity) focused on optimizing the gravity-powered apparatus.

## Methods

### Experimental Apparatus

The gravity-powered apparatus was constructed using 80/20 T-slotted aluminum bars (Figure 2). Fabrication details can be found in the Manual section below.

### Head Loss Calculations

The flow rate through the gravity-powered apparatus depends on piezometric head. Thus, by altering the height differences in the system, flow rate can be manually adjusted (Figure 4, Figure 5).  

#### System Flow Rate
$Q_{PACl} C_{PACl} = Q_{system} C_{system}$

Water in the gravity-powered system flows from the fluoride stock tank, to the fluoride constant head tank, to the flocculator, up the sedimentation tube, and out the effluent line.



**Figure 5:** The system flow rate is determined by the height difference between the water level of the fluoride constant head tank and the effluent line. The height difference, and thus the flow rate, can be controlled by the adjustable slider on effluent line.

There are multiple sources of head loss in this system: major head loss in the tubing and minor head loss in the flocculator.

To find major head loss in the straight sections of tubing we will be utilizing the Hagen–Poiseuille equation:

$\Delta H_1 =\frac{32\mu LV}{\rho gd^2}$

Where $L$ is the length of the tube, $V$ is the bulk velocity of the system, and $d$ is the diameter of the tubing.

To find the head loss in the coiled flocculator we will utilize the following equation:

$\Delta H_2 = \frac{32\mu VL}{\rho gd^2} 0.37 De^{0.36}$

Where $De$ is the Dean Number, found experimentally by C.M White ([Garber, 2004](https://www.seas.upenn.edu/~belab/LabProjects/2004/be310s04m5.doc)). It is a dimensionless quantity that establishes a relationship between the inertial, centripetal, and viscous forces in a fluid, and is used to find the pressure drop in a coiled tube. It represented by the following expression:

$De=Re\sqrt\frac{D}{d}$

Where $Re$ is the Reynolds Number:

$Re=\frac{\rho VL}{\mu }$

Therefore,

$\Delta H_2 = \frac{32\mu VL}{\rho gd^2} 0.37 (\frac{\rho VL}{\mu }\sqrt\frac{D}{d})^{0.36}$

The total head loss for the system flow rate will be:

$\Delta H_{tot}=\Delta H_1 + \Delta H_2$

#### Coagulant Flow Rate


**Figure 6:** The flow rate of PACl is determined by the height difference between the water level of the fluoride constant head tank and the water level of the coagulant constant head tank. The height of the PACl constant head tank can be adjusted, which allows for user control of the PACl flow rate.

To calculate the required height difference between the water level of the fluoride constant head tank and the water level of the coagulant constant head tank, the following equations were used:

First, the energy equation was applied from the PACl constant head tank to the connection junction point at $H_3$. Note that the tubing used to connect to the PACl tank is microbore tubing.

$\frac{P_C}{\gamma} + \frac{V_C^2}{2g} + H_1 = \frac{P_D}{\gamma} + \frac{V_D^2}{2g} + H_3 + H_t$

* The $\frac{P_C}{\gamma}$ term can be ignored since the container is open to the atmosphere so gauge pressure at C is zero.

* $\frac{V_C^2}{2g}$ also drops out because the velocity at point C can be assumed to be zero.

* $H_t$ describes total head loss

Applying these assumptions, the following expression was obtained:

 1) $H_1 - H_3 = \frac{P_D}{\gamma } + \frac{V_D^2}{2g} +H_t$

Then, the Bernoulli Equation was applied from the fluoride constant head tank to the connection junction. This was done assuming that the head loss from the tubing was negligible since it has a diameter of $\frac{1}{4}$ inches and its length is very small.

$\frac{P_A}{\gamma}+ \frac{V_A^2}{2g} + H_2 = \frac{P_B}{\gamma} + \frac{V_B^2}{2g} + H_3$

* Similarly, the $\frac{P_A}{\gamma}$ term can be ignored since the container is open to the atmosphere so gauge pressure at A is zero.

* $\frac{V_A^2}{2g}$ also drops out because the velocity at point A is zero due to a float valve that keeps the water level constant.

Applying these assumptions, the following is obtained:

2) $P_B= \gamma(H_2-H_3 -\frac{V_B^2}{2g})$

The pressures going into the junction were assumed to be equal:

3) $P_B =P_D$

Combining equations 1, 2 and 3, the following expression is obtained:

$H_1 - H_3 = \frac{\gamma(H_2-H_3 -\frac{V_B^2}{2g})}{\gamma } + \frac{V_D^2}{2g} +H_t$

Which can be simplified to:

$H_1 - H_2 = -\frac{V_B^2}{2g} + \frac{V_D^2}{2g} + H_t$

Thus, the desired head for the PACl tank is:

$\Delta h = -\frac{V_B^2}{2g} + \frac{V_D^2}{2g} + H_t$

Additionally, using the desired fluoride flow rate through the system of 0.76 mL/s, and desired maximum PACl flow rates (which was estimated to be 1% of the system flow rate), it was determined that both $\frac{V_B^2}{2g}$ and $\frac{V_D^2}{2g}$ are less than 1% of total head loss and therefore can be ignored.

 Finally, the height difference between the coagulant constant head tank and the fluoride constant head tank is shown to be just the sum of all the head loss:

$\Delta h = H_t$

Where $H_t$ is described by the major and minor losses encountered from the PACl constant head tank to the connection junction,

$H_t= h_{major} + h_{minor}$

$H_t= \sum \frac{V^2}{2g}(\sum f\frac{L}{D}+\sum K_L)$
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

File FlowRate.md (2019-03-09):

Calculations for flow rates into system.
Fluroide has been running at 1.5 mm/s upflow velocity which is roughly .076 mL/s of volumetric flow. Your volumetric flow of fluoride and PACL should add together to somewhere around .076 mL/s.
```python
import math as m
import numpy as np
from aguaclara.play import*
#Input your concentrations you want your system to run at and the upflow velocity in your sed tube
Conc_PACl_exp = 40 * (u.milligram / u.liter)#PACl concentration in your experiment
upflow_velocity = 1.5 * (u.millimeter / u.second)
#Change the above parameters for what you want in your experiment
#Input your concentrations of your stock tanks
Conc_PACl_stock = 1000 * (u.milligram / u.liter)
Conc_fluoride_stock = 100 * (u.milligram / u.liter)

D_sed_tube = 1*u.inch
Area_sed_tube = np.pi*(D_sed_tube**2)/4
Q_system = Area_sed_tube * upflow_velocity
Q_system.to(u.milliliter/u.second)
Q_PACl = (Q_system * Conc_PACl_exp / Conc_PACl_stock).to(u.milliliter/u.second)
print(Q_PACl)
Q_fluoride = (Q_system-Q_PACl)
conc_fluoride_exp = Conc_fluoride_stock * Q_fluoride / Q_system
print(conc_fluoride_exp)
```

So ideally for your experimental setups with fluoride you should know the concentrations of both of your stock tanks that will flow into the system. Fluoride subteams have been using 1.5 mm/s of upflow velocity but you can change this if you would like. The above code should tell you the flowrate of PACl you want into your system, Sarah's code should then correlate that Q into a height difference between the PACl constant head tank and the drip chamber for your system. It will also tell you the fluoride concentration within the experiment that you are working with.

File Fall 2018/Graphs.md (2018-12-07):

# Graphs

This shows the Python code used to make graphs:

```Python

import matplotlib.pyplot as plt
%matplotlib inline
import numpy as np
from scipy import stats

#x coordinates are the height difference between fluoride constant head tank and PACl constant head tank
#y coordinates are the measured flow rates

data_points = np.array([[5, 0.00991333],
                       [10,0.0158],
                       [15,0.0269333],
                       [20,0.03577]])

x_points = data_points[:,0]
y_points = data_points[:,1]

linreg = stats.linregress(x_points, y_points)
slope, intercept, r_value = linreg[0:3]

start = x_points[0] # Change as desired
end = x_points[-1] # last element plus one; change as desired
plt.plot(x_points, y_points, 'o')
plt.plot(np.arange(start,end,0.1), np.arange(start, end,0.1)*slope + intercept)
plt.xlabel('Height Difference between Fluoride Constant Head Tank and PACl Constant Head Tank (cm)')
plt.ylabel('Measured Flow Rate (mL/s)')
plt.title('Measured Flow Rates at Varying Height Differences')
plt.minorticks_on()
plt.grid(which = 'major')
plt.grid(which = 'minor')
plt.savefig("flow_rate1.png",dpi=1000)
plt.show()

print("Slope:", slope)
print("Intercept:", intercept)
print("R-squared:", r_value ** 2)

```

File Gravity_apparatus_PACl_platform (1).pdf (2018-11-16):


25 cm

15 cm

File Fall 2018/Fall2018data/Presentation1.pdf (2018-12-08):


# Effect of Iron Presence on the Algae Growth

## Introduction

In this study, the effect of iron (in the form of ferric citrate) on the growth of

algae was investigated. The uptake of iron in microalgae populations is of

ecological importance and many microalgae species are able to reduce iron and

store iron intracellularly. Iron is used by algae for metabolism and in the cellular
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

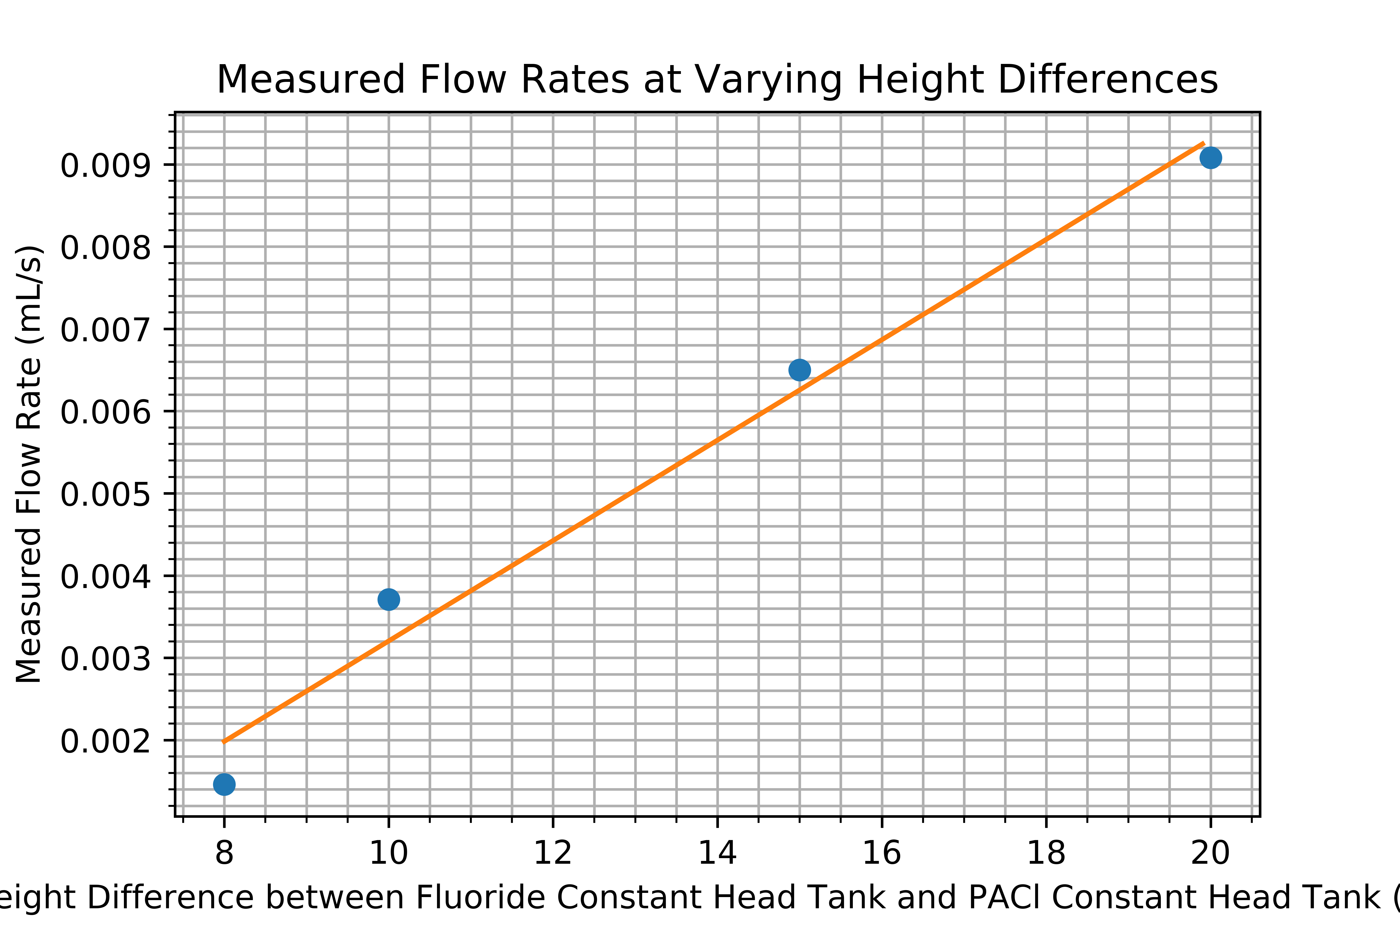
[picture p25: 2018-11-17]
flow_rate1.png

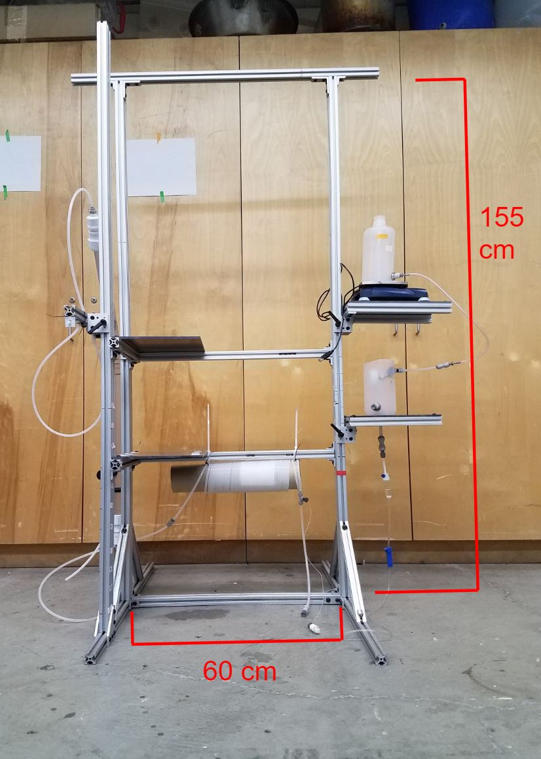
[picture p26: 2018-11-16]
Fall 2018/Gravity_apparatus_front.JPG

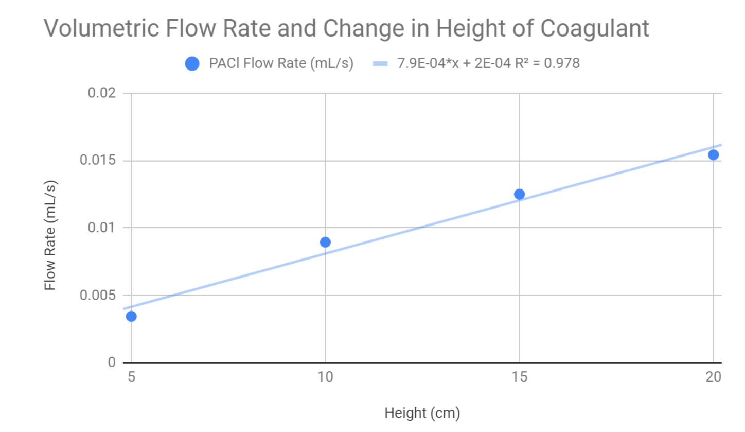
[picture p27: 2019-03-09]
Spring 2019/PACl vs height.PNG

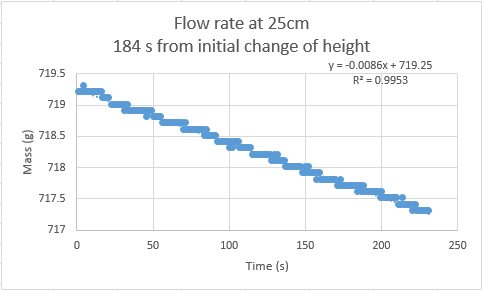
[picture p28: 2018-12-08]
Fall 2018/Fall2018data/Scale_flow_rate_25cm_adjusted.PNG

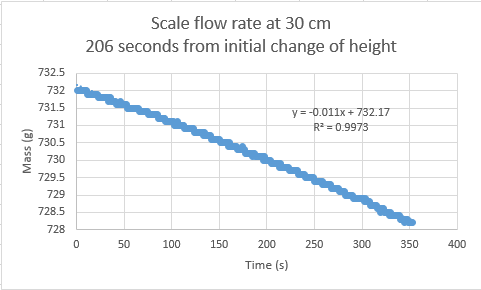
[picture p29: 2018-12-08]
Fall 2018/Fall2018data/Scale_flow_rate_30cm_height_adjusted.PNG

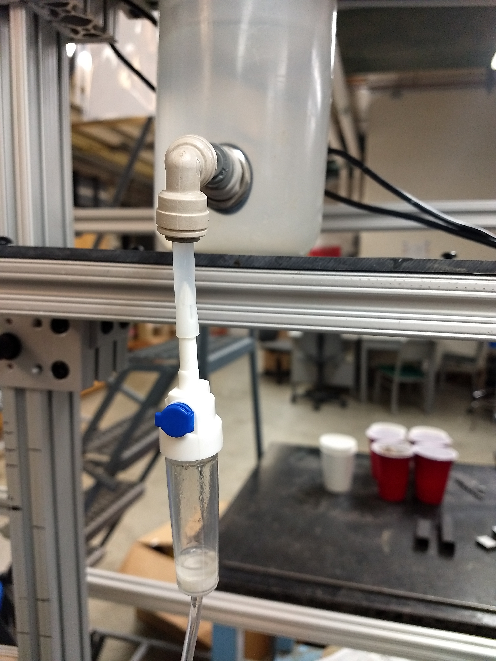
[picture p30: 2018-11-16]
Fall 2018/iv_system.jpg

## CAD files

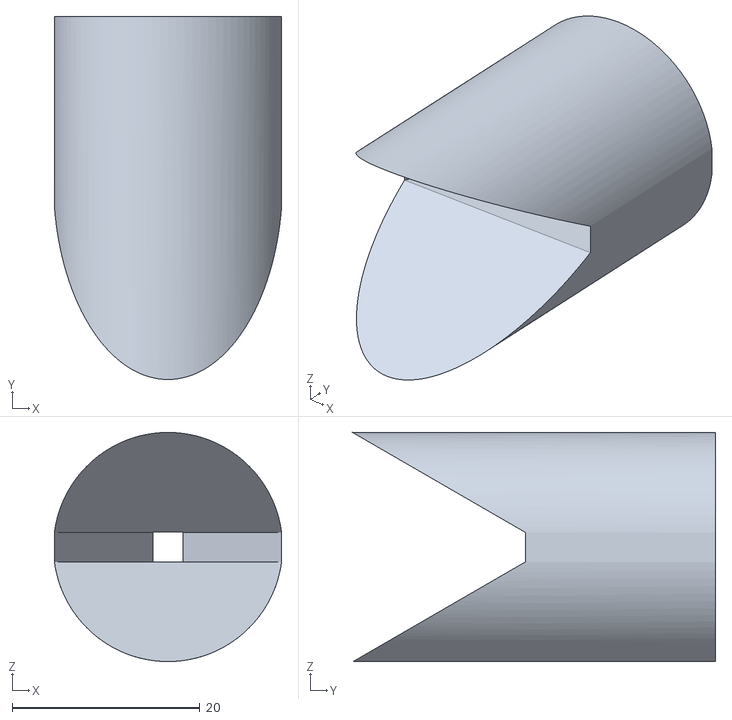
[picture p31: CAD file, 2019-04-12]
Spring 2019/BotGeo.stl
24.2 x 38.7 x 24.4

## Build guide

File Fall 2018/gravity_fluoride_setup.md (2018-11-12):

```python
"""Contains functions pertaining to the design of the gravity-powered fluoride removal experimentation apparatus.
"""

import math as m
import numpy as np
from aide_design.play import*

G = 9.80665 * u.m/u.s**2
"""Define the gravitational constant, in m/s²."""

#@u.wraps(u.m**2, u.m, False)
def required_height(q_sys, d_sys, d_micro, l_micro, q_PACl):

  """Returns height difference (delta_h) between the water level in the fluoride constant head tank and the water level in the PACl constant head tank.

  Parameters
  ----------
  T:  scalar (float) (optional argument)
      Temperature of water

  q_sys:  scalar (float)
      Flow rate through system

  d_system: scalar (float)
      Diameter of system tubing i.e. tubing from fluoride constant head tank to flocculator

  d_micro:  scalar (float)
      Diameter of microbore tubing from PACl constant head tank to T-joint where PACl mixes with fluoride

  l_micro:  scalar (float)
      Length of microbore tubing

  q_PACl: scalar (float)
      Desired flow rate of PACl

  """
  #calculate dynamic viscosity and water density
  T=298*u.K
  mu = pc.viscosity_dynamic(T)
  rho = pc.density_water(T)

  #calculate cross-sectional area of microbore tubing
  a_micro = pc.area_circle(d_micro)

  #calculate cross-sectional area of system tubing
  a_sys = pc.area_circle(d_sys)

  #calculate required height difference
  #This equation was derived from the modified Bernoulli equation, accounting for head loss due to friction through the microbore tubing.

  delta_h = -1/(2*G)*((q_sys-q_PACl)/a_sys)**2 + ((q_PACl/a_micro)**2)/(2*G) + (32*mu*l_micro*(q_PACl/a_micro))/(rho*G*d_micro**2)

  return delta_h

q_sys = (0.76*u.mL/u.s).to(u.m**3/u.s)
d_sys = (3/16*u.inch).to(u.m)
d_micro = (0.022*u.inch).to(u.m)
l_micro = (78*u.cm).to(u.m)
q_PACl = (0.01583*u.mL/u.s).to(u.m**3/u.s)

required_height(q_sys, d_sys, d_micro, l_micro, q_PACl)

```

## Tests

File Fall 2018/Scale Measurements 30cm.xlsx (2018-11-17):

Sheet: Raw Data
Raw Data
Time | Mass
0 | 733.6
1 | 733.6
2 | 733.6
3 | 733.6
4 | 733.6
5 | 733.6
6 | 733.6
7 | 733.6
8 | 733.6
9 | 733.5
10 | 733.6
11 | 733.6
12 | 733.6
13 | 733.6
14 | 733.6
15 | 733.5
16 | 733.5
17 | 733.5
18 | 733.5
19 | 733.5
20 | 733.5
21 | 733.5
22 | 733.5
23 | 733.5
24 | 733.5
25 | 733.5
26 | 733.5
27 | 733.4
28 | 733.5
29 | 733.5
30 | 733.5
31 | 733.5
32 | 733.4
33 | 733.5
34 | 733.5
35 | 733.5
36 | 733.4
37 | 733.4
38 | 733.4
39 | 733.4
40 | 733.4
41 | 733.4
42 | 733.4
43 | 733.4
44 | 733.4
45 | 733.3
46 | 733.4
47 | 733.3
48 | 733.3
49 | 733.3
50 | 733.3
51 | 733.3
52 | 733.3
53 | 733.3
54 | 733.3
55 | 733.3
56 | 733.3
57 | 733.3
58 | 733.3
59 | 733.2
60 | 733.2
61 | 733.3
62 | 733.3
63 | 733.3
64 | 733.3
65 | 733.2
66 | 733.2
67 | 733.1
68 | 733.2
69 | 733.2
70 | 733.2
71 | 733.2
72 | 733.2
73 | 733.2
74 | 733.1
75 | 733.1
76 | 733.1
77 | 733.1
78 | 733.1
79 | 733.1
80 | 733.1
81 | 733.1
82 | 733.1
83 | 733.1
84 | 733.1
85 | 733.1
86 | 733.1
87 | 733.1
88 | 733.1
89 | 733.1
90 | 733
91 | 733
92 | 733
93 | 733.1
94 | 733
95 | 733
96 | 733
97 | 733
98 | 733
99 | 733
100 | 733
101 | 733
102 | 732.9
103 | 733
104 | 733
105 | 733
106 | 733
107 | 733
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

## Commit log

2018-12-07 added sed tube bottom geo, future work
2018-12-08 Procoda data
    [10 cm scale calculation nov27.txt.xlsx, 10mgl scale calculations.xlsx, 15 cm scale calculation nov27.txt.xlsx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]
2018-12-08 Update image of 3D printed insert
2018-12-08 Updated botgeo para
2019-02-21 Update Spring 2019 Report.md
2019-03-15 Update Spring 2019 Report.md
    Corrected Introduction and figure numbers. Added to the results section.
2019-04-12 Added Botgeo file.
    [BotGeo.stl]
2019-04-25 add langmuir data
    [Langmuir Isotherm 2.xlsx]
2019-04-27 Added Botgeo drawing,T-Junction obs, new effluent flow rate graph
2019-05-07 current schematic
